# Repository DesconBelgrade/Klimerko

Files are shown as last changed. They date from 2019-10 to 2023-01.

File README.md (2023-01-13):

# “Klimerko” Air Quality Monitoring Station

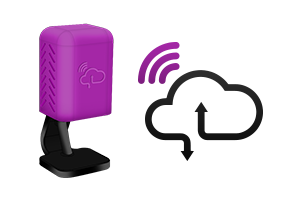
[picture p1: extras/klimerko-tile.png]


"Klimerko" is the continuation of the [Winning Project from Descon 4.0 2018](https://descon.me/2018/winning-product/).  

See live data from all Klimerko devices: [Klimerko.org](https://klimerko.org)

This is an affordable DIY air quality station that measures [Particulate Matter](https://www.epa.gov/pm-pollution/particulate-matter-pm-basics) concentration as well as Temperature, Humidity and Pressure.  
It publishes data to your [AllThingsTalk Maker Cloud](https://www.allthingstalk.com/maker) (free) where you're able to visualize data, see it historically and control the device.   
Continue reading to find out how to build your own, or watch the video below that covers the process.
  
> ***NOTICE:*** The video was created before the release of Klimerko Firmware v2.0.0, which introduced WiFi Configuration Mode, so the process of connecting the device to WiFi and AllThingsTalk shown in the video is outdated.

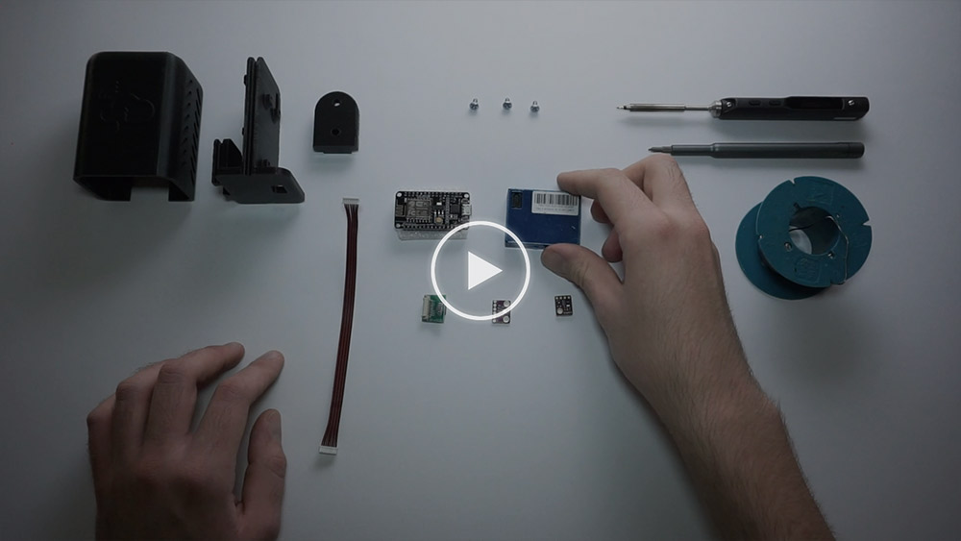
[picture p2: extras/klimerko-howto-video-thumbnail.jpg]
YouTube Video: Kako napraviti klimerka? (https://www.youtube.com/watch?v=D9VHvuHtT14)


**Having issues? Go to the [Troubleshooting](#troubleshooting) section.**  
**To update your Klimerko, go to [Updating Firmware](#updating-firmware)**.

# Table of Contents
This guide is in chronological order, so try not to skip through parts if you're not sure about it.

* [Hardware Build](#hardware-build)
  * [Hardware Required](#hardware-required)
  * [Tools Required](#tools-required)
  * [3D Case Preparation](#3d-case-preparation)
  * [PMS7003 Sensor Preparation](#pms7003-sensor-preparation)
  * [BME280 Sensor Preparation](#bme280-sensor-preparation)
  * [NodeMCU Preparation](#nodemcu-preparation)
* [Cloud Platform (1/2)](#cloud-platform-12)
* [Software](#software)
  * [Installing ESP8266 Support](#installing-esp8266-support)
  * [Uploading Firmware](#uploading-firmware)
  * [Configuring Klimerko Credentials and Temperature Offset](#configuring-klimerko-credentials-and-temperature-offset)
* [Cloud Platform (2/2)](#cloud-platform-22)
  * [Configure Device](#configure-device)
  * [Share Data](#share-data)
  * [Visualize Data](#visualize-data)
* [Updating Firmware](#updating-firmware)
  * [Updating Wirelessly (OTA)](#updating-wirelessly-ota)
  * [Updating using Arduino IDE](#updating-using-arduino-ide)
* [Toubleshooting](#troubleshooting)
  * [Use Serial Monitor](#use-serial-monitor)
  * [Compilation issues](#compilation-issues)
  * [Klimerko can't see WiFi network](#klimerko-cant-see-wifi-network)
  * [Can't connect to Klimerko to configure it](#cant-connect-to-klimerko-to-configure-it)
  * [Klimerko isn't connecting to WiFi or AllThingsTalk](#klimerko-isnt-connecting-to-wifi-or-allthingstalk)
  * [Assets not being updated](#assets-not-being-updated)
  * [Klimerko won't turn on](#klimerko-wont-turn-on)
  * [Factory Reset your Klimerko](#factory-reset-your-klimerko)

# Hardware Build
This diagram shows an overview of how Klimerko works
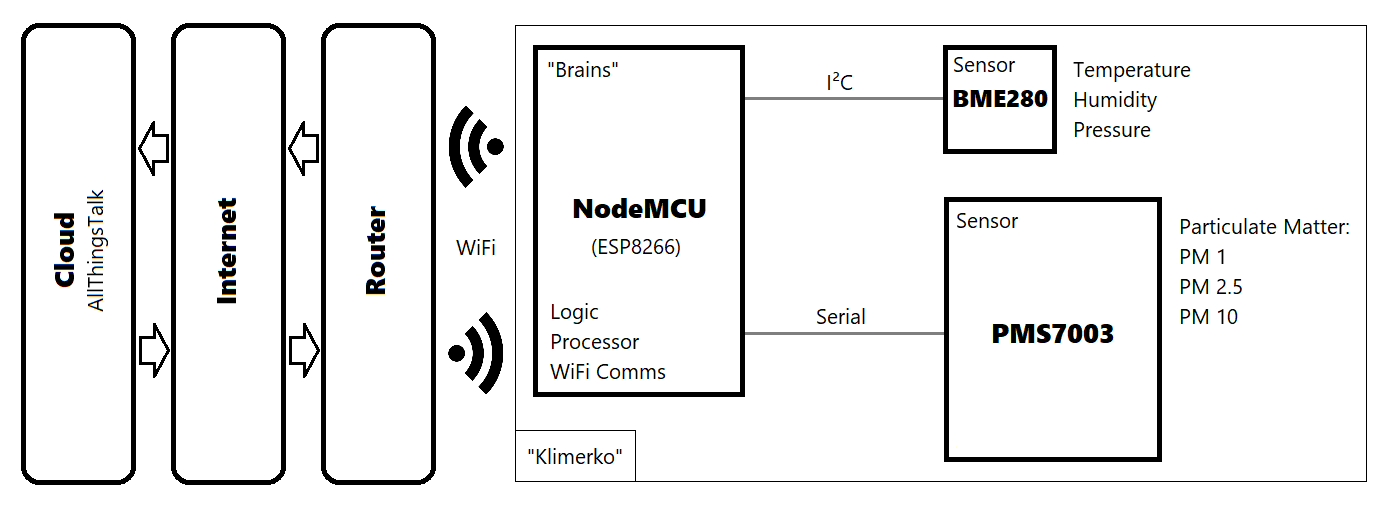
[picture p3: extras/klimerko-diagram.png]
Klimerko Diagram


## Hardware Required

You'll need these components to follow this guide: 

> Previously, some of the components below were clickable so you could buy them right away, but shipping to Balkans on some websites became 10x more expensive than the components themselves, therefore the list now only contains the names, description and a photo of the items you need to buy.  
You can search for these components on [eBay](https://ebay.com), [Banggood](https://banggood.com), [AliExpress](https://aliexpress.com) or your local electronics store/website.

- **NodeMCU (Amica, with CP2102 chip)**  
  Try to avoid the cheapest ones as they're using a different pinout and a weaker CHG340 chip.  
  It should look exactly like this:  
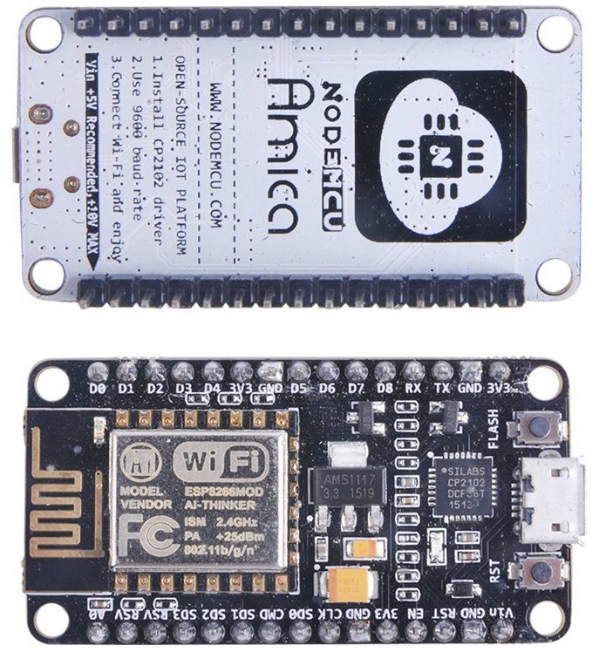
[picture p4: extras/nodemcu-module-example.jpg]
  

- **Plantower PMS7003 Air Quality Sensor**  
  Get the one with a connector and a bridge board.  
  Should look exactly like this:  
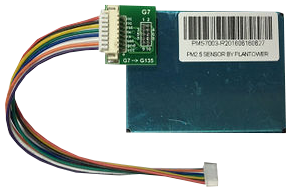
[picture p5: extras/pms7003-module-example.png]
  

- **Bosch BME280 Temperature/Humidity/Pressure Sensor**  
  Make sure to get the BM**E**280 and ***not*** the cheaper BM**P**280.  
  There are variants with 6 pins, and if you find them to be cheaper than the ones with 4 pins (as shown below), you can buy that as well - you just won't use additional 2 pins.  
  It should look exactly like this:  
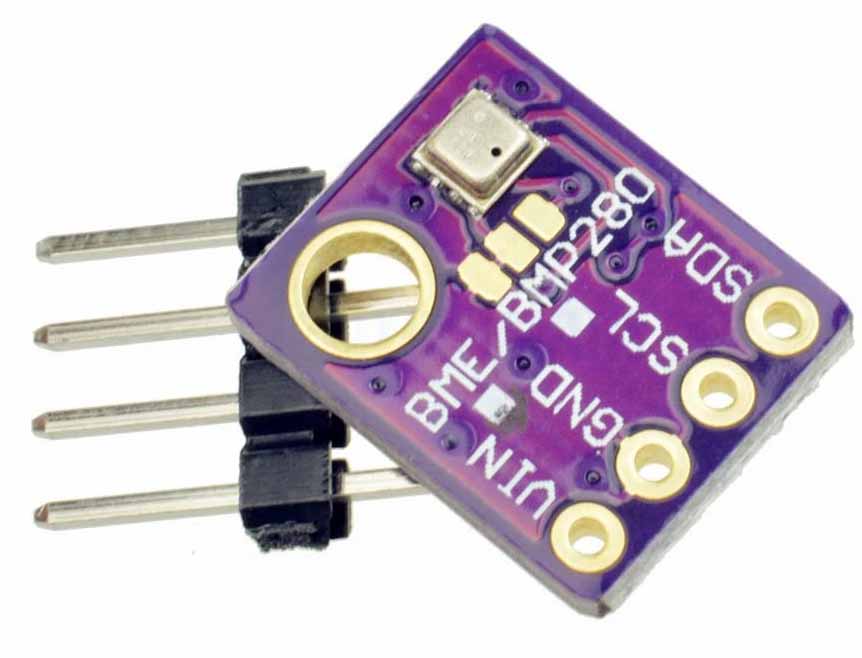
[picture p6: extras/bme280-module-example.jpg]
  

- USB Power adapter (5V, minimum 250mA/0.25A)
- MicroUSB Cable
- **4x** Wires (each at least 13cm long)
- ***Optional:*** 3D printed case for the device ([STL Files](https://github.com/DesconBelgrade/Klimerko/tree/master/Klimerko_Printable_Case)), which comprises of:
    - Components base
    - Weather-resistant cover
    - Flat stand
    - Wall-mount holder
    - Non-3D-Printed: **5x** Screws (for plastic, 3x5mm) (**7**x screws if you’re going to wall-mount the device)

## Tools Required

You’re going to need the following tools at minimum to complete the project:

- Soldering Iron
- Solder
- Scissors or a Wire Stripper
- Screwdriver (required only if using 3D printed case)

## Hardware Assembly

Once you’ve got all the components and tools ready, it’s time to begin the assembly process.  
  
When soldering, make sure that there's no solder between any two pins (connection holes in the board) on any of the components **before** plugging the device into a power source.  
**Pay attention to VIN and GND** pins on the NodeMCU, because shorting (connecting) those two pins together **will fry** NodeMCU and possibly the power source it's connected to.

## 3D Case Preparation

> You can print your own Klimerko Case using a 3D Printer using the [3D Print Files](https://github.com/DesconBelgrade/Klimerko/tree/master/Klimerko_Printable_Case). If you don't have a 3D Printer, your local hacker/makerspace most likely has one!

> In case you're not following this guide at a workshop: 
> You're still able to build this device if you don't have the 3D case. You'll just need to tinker and figure out how to place the device in a secure location away from rain/sun (but in an open space so it can detect pollution properly) 

Depending on your use case, you can use either the flat stand or the wall-mounted holder.
If you wish to wall-mount the device, use 2 screws to mount the holder to a wall. You’ll be able to easily attach and detach the device from the wall.

For now, disassemble the case and put away all the parts except for the components base, where you’ll be placing all the components.

## PMS7003 Sensor Preparation

- First, make sure **not** to remove the blue plastic cover from the PMS7003 sensor as it helps it fit into the 3D case better.
- Place the PMS7003 sensor into the components base of the 3D case with the connection port of PMS7003 facing outwards in upper right side.  
- Plug in the connector cable into the bridge board.  
- Because we don’t need excess cabling, removal of the unnecessary wires from the connector cable is suggested. In order to know which wires to pull, make sure the connector cable is plugged into the bridge board so that you can see the markings on the board that correspond to the wires. To remove the wires, pull them with medium force until they’re detached from the connector. 
These are the wires to pull (marked red):
    - **NC** (first one)
    - **NC** (second one)
    - **RST**
    - **SET**
    The only wires left attached should be **TX**, **RX**, **GND** and **VCC**.

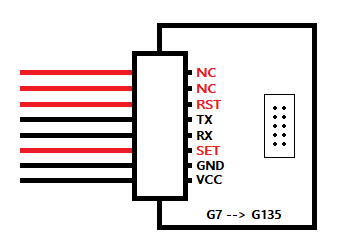
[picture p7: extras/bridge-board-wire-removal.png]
Bridge Board Wire Removal

    
- Measure ~13cm of all 4 remaining wires from the connector cable and cut the rest, so you’re left with the connector at one end and cut wires on the other.
- Using scissors or a wire stripper, remove the insulation ~2mm from the end of each wire, so you’re left with clear copper at the ends.
- Plug the bridge board (with the connector cable in) into the PMS7003 Sensor.
- Route the wires through the circular hole in the components base of the 3D case so it reaches the other side of the base.

## BME280 Sensor Preparation
- Take the 4 wires you have prepared (not to be confused with the PMS7003 wires) and strip (remove insulation) ~2mm from each end of each wire so that you have 4 wires with all ends stripped.
- Solder those 4 wires to pins **SDA**, **SCL**, **GND**, **VCC/VIN** on the BME280.  
  **If you have a 6-pin version of BME280, the CSB and SDO pins simply aren't used.**
- Make sure the PMS7003 Sensor is seated properly (because BME280 goes above it), and only then proceed to the next step.
- Mount the BME280 sensor in place by screwing it to the hole in the upper right side of the 3D case (above the PMS7003).
- Route the wires through the circular hole in the components base of the 3D case so it reaches the other side of the base.

You have now completed the setup of the sensor side of the components base.
Next up, the NodeMCU side.

## NodeMCU Preparation

You should now have 8 wires coming through the circular hole leading to the NodeMCU side of the 3D case.

- Solder the wires to the NodeMCU board:

> Please double check to make sure you’re soldering the correct wires (coming from the sensors) to the NodeMCU board.

| Sensor  | Sensor Wire | NodeMCU Pin |
| --- | --- | --- |
| PMS7003 | VCC | VIN |
| PMS7003 | GND | GND (Any GND pin works) |
| PMS7003 | RX | D6 |
| PMS7003 | TX | D5 |
| BME280  | VCC/VIN | 3v3 (Any 3v3 pin works) |
| BME280  | GND | GND (Any GND pin works) |
| BME280  | SCL | D1 |
| BME280  | SDA | D2 |

> You have now finished all steps that require soldering.

- Now use 4 screws to place the NodeMCU in its spot in the components base of the 3D case.
- Double check all the connections and if everything is as it should be.
- Put the weather-resistant cover of the 3D case over the components base (it's better to do this once everything is done and device is connected, though)

Congratulations, you’ve assembled the device! Now onto the software side.

# Cloud Platform (1/2)
- Head over to [AllThingsTalk Maker](https://maker.allthingstalk.com) and create a free account
- Sign in
- Click “Playground”
- In "Devices", click "+ New Device"
- Choose “Descon Klimerko”
- Click “Settings” in the upper right corner
- Click “Authentication”
- Write down your **Device ID** and **Device Token**

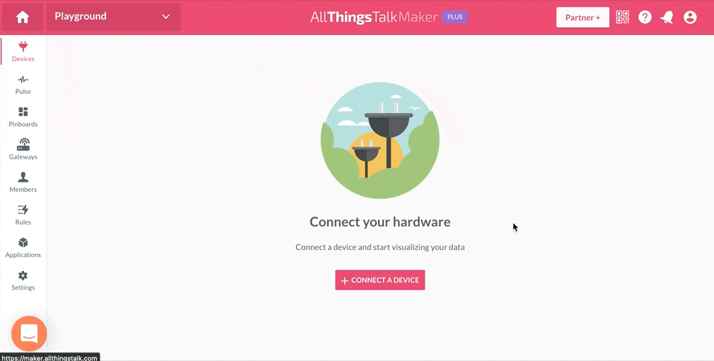
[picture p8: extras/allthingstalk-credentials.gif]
Cloud Credentials


# Software
For all of the steps below, you'll need Arduino IDE (Integrated Development Environment).  
This is a tool that's used to send the "firmware" or "program" to your device.  

> If you already have Arduino IDE, make sure it's **at least** version 1.8.15

- Download and install [Arduino IDE](https://www.arduino.cc/en/software) 
(choose “*Windows installer, for Windows XP and up*” if you’re on Windows, otherwise it'll download the Windows Store version, which might give you issues).

- If you're on **Microsoft Windows**, [download and install the CP2102 Driver for Windows](https://www.silabs.com/documents/public/software/CP210x_Universal_Windows_Driver.zip).

- If you're on **Apple's MacOS**, [download and install the CP2102 Driver for MacOS](https://www.silabs.com/documents/public/software/Mac_OSX_VCP_Driver.zip).

## Installing ESP8266 Support
ESP8266 is the "brains" or "processor" of the NodeMCU, but Arduino IDE doesn't support it out-of-the-box. That's an easy one:
- Open Arduino IDE
- Go to *File* > *Preferences*
- In the *Additional Boards Manager URLs*, enter `http://arduino.esp8266.com/stable/package_esp8266com_index.json` and click *OK*
- Go to *Tools* > *Board* > *Boards Manager*
- Search for “*esp8266*” by *ESP8266 Community*
- Click *Install*
- Once done, close the window.

## Uploading Firmware
Your NodeMCU's "brain" is empty at the moment. Let's teach it what it needs to do by uploading the program to it:

- Plug in the USB cable into your Klimerko device and your computer
- Download https://github.com/DesconBelgrade/Klimerko/archive/master.zip
- Unzip the file, open it and go to “Klimerko_Firmware” folder
- Open “Klimerko_Firmware.ino” with Arudino IDE
- Now go to *Tools* > *Board* and choose “*NodeMCU 1.0 (ESP-12E Module)*”
- Go to *Tools* > *Upload Speed* and choose *115200*
- Go to *Tools* > *Port* and you should see **COM** and a number next to it. Choose it.
  - If you have multiple COM ports available and the one you've chosen doesn't work, try the other ones as well.
  - If you're running **MacOS**, choose */dev/cu.SLAB_USBtoUART*
- Go to “Sketch” > “Upload” and wait for the firmware to be uploaded to your Klimerko device

## Configuring Klimerko Credentials and Temperature Offset
> Since Klimerko Firmware version 2.0.0, the process of entering WiFi & Platform credentials has been immensely simplified by introducing WiFi Configuration Mode, a feature where Klimerko itself becomes a WiFi Access Point to which you can connect to using your computer or smartphone and then configure the credentials using a simple web interface that opens up automatically once you're connected to your Klimerko.  

You need tell your Klimerko which credentials to use to connect to the platform and to which WiFi to connect to: 

- Make sure your Klimerko is connected to power.
- Lift your Klimerko's cover to expose the NodeMCU board.
- Press and hold the **FLASH** button for 2 seconds and then let go.
- The blue LED on the NodeMCU should turn on and stay on. This indicates the WiFi Configuration Mode is currently active and you can connect to your Klimerko.
- Using your computer or a smartphone, search for and connect to WiFi Network ***"KLIMERKO-XXX"*** (the X's are numbers) using password **"ConfigMode"**.
- Your device should automatically open Klimerko's WiFi Configuration Portal. If it doesn't, navigate to **[192.168.4.1](http://192.168.4.1)** in your browser. 
- Click the first **"Configure WiFi"** button.
- A list of available WiFi Networks will be shown, along with a field to enter your AllThingsTalk Device ID and Device Token.
  > NodeMCU only supports 2.4GHz, so make sure the network you're trying to connect your Klimerko to **is not** a 5GHz network.
- Select your WiFi network from the list (or manually enter WiFi network name if you're not in range of the network you plan to use your Klimerko on), enter your WiFi Password and copy/paste the AllThingsTalk Device ID and Device Token that you noted in previous step ([Cloud Platform Credentials](#cloud-platform-12))
  > If you are updating your credentials, it is possible to only update some of them by leaving other fields empty. The empty fields will not overwrite the values stored in memory when saving.
- You can set a custom **Temperature Offset** if you wish. This will affect temperature readings from the device and humidity readings will be compensated for the temperature offset as well.
  > Configurable Temperature Offset has been introduced in Firmware Version 2.1.0. The default offset is `-4°C`. Decimals, negative and positive values are supported (e.g. `-1.2`, `3.58`, `+3.58`, `-7.43`). Positive values can be set with or without the `+` prefix. The maximum positive offset is 25°C, and maximum negative is -25°C. If you wish to use the default value, simply leave the **Temperature Offset** field as it is. As opposed to WiFi Credentials and AllThingsTalk Credentials, the Temperature Offset field always displays the currently used value.
- Click ***"Save"***. 
- Klimerko has now automatically shut down the WiFi Configuration Mode (the blue LED stops shining constantly) and your computer/smartphone will disconnect from "KLIMERKO-XXX" network. The WiFi Configuration Portal will automatically close on your computer/smartphone only if it was automatically opened. Otherwise, you'll need to close the browser tab.
- Your Klimerko will now attempt to connect to WiFi and AllThingsTalk, indicated by slow blinking of the LED light.
- Observe the LED on the NodeMCU. If it blinks quickly a few times and then turns off completely, your Klimerko is connected to both WiFi and AllThingsTalk. Otherwise, repeat the process (the credentials could be incorrect) or check the [Troubleshooting section](#troubleshooting).

> The blue LED light on NodeMCU blinks slowly (in 1 second intervals) when Klimerko is trying to connect to WiFi or AllThingsTalk (or if the connection can't be established).  
If it blinks rapidly a few times and then turns off, the connection to WiFi and AllThingsTalk has been made succesfully.  
If it's turned on constantly, it means the WiFi Configuration Mode is currently active and you can connect to your Klimerko using your smartphone.  
If you wish to turn off WiFi Configuration Mode without configuring your Klimerko, press the ***"FLASH"*** button on your NodeMCU quickly, once. The constant blue LED should turn off.

# Cloud Platform (2/2)

All of the data from your Klimerko is available on your AllThingsTalk Maker.  
Other than raw actual and historical air quality values, you’re able to see your air quality in a textual form at a glance, see the WiFi Signal Strength of your Klimerko and control how often your Klimerko publishes data.  
You’ll also get notifications if your Klimerko goes offline for any reason.

## Configure Device

Open [AllThingsTalk Maker](https://maker.allthingstalk.com), go to “Devices” and select your new “Descon Klimerko” device.  
You’ll see all assets of your device (stuff that it can report and things you can control).

> Make sure to keep the data (that you’re about to set below) updated if you move your device

- Click on the “Location” asset and select the location of your Klimerko on the map
- Click on the “Height” asset and set the height of your device (in **meters**) by adding a value right next to `"value":`  and clicking the ✔️ button when done (below is an example of 10 meters height):
```
    {
        "at": "2019-10-18T11:28:04.554Z",
        "value": 10
    }
```
This needs to be done since air pollution readings are different on different heights.

## Share Data

Go to your “Decon Klimerko” device, click “Settings” in the upper right corner, go to “Share data” and share your data with “**Vazduh gradjanima**”.  
Your device will now be visible on the map at [Klimerko.org](https://klimerko.org) and can help the community be aware of the air quality!  

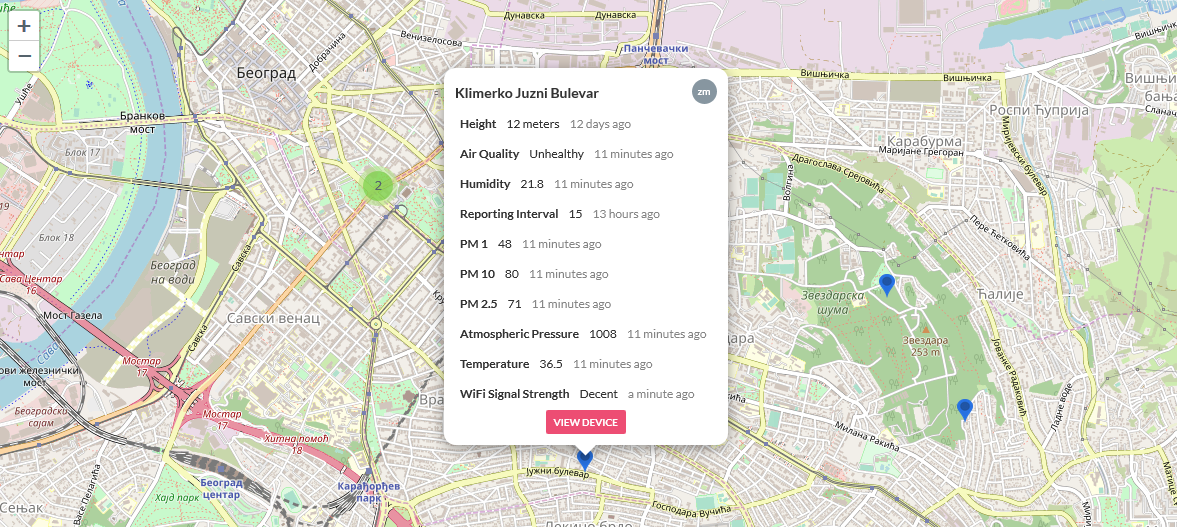
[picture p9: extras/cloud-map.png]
Cloud Map
 

## Visualize Data

Now go to “Pinboards” on the left side of AllThingsTalk Maker.  
You should see a new pinboard named “Klimerko”. Select it if it isn’t already selected.  
All data from your Klimerko is visualized here:

- Air Quality (in textual form)  
    Value shown will also have a corresponding background color.  
    This value is derived from PM10 values (as per [regulations of Republic of Serbia](http://www.amskv.sepa.gov.rs/kriterijumi.php)):
    
| Textual Value | PM 10 Value |
| --- | --- |
| Excellent | 0 - 20 |
| Good | 21 - 40 |
| Acceptable | 41 - 50 |
| Polluted | 51 - 100 |
| Very Polluted | 100 > |

- Actual PM1, PM2.5, PM10, Temperature, Humidity and Pressure data
- Historical PM1, PM2.5, PM10, Temperature, Humidity and Pressure data
- Location of your device on the map (that you’ve set)
- WiFi Signal Strength of your Klimerko device  
    Possible values (from good to bad): Excellent, Good, Decent, Bad, Horrible.  
    The values shown will also have a corresponding background color.
- Device height (that you’ve set)
- Device reporting interval (minutes)  
    You can use this slider to control how often your Klimerko reports its data to AllThingsTalk. The default and recommended value is 15 minutes.

**You’re done!**  
Enjoy your device and feel free to visit [Klimerko.org](https://klimerko.org) and see your device along with all the other devices just like yours that are helping others be aware of the air pollution in your area!

# Updating Firmware
This step is for those who've already built their Klimerko and wish to update its firmware to the latest version.  

To check what Firmware version your Klimerko is on, you can:
  - Open your Klimerko device on your [AllThingsTalk Maker](https://maker.allthingstalk.com):  
  The Firmware Version will be stored in the "Firmware Version" asset.  
  - Use Serial Monitor in Arduino IDE:  
  Klimerko will output the Firmware Version in the first few lines once it boots.
  - *Version 2.0.0 and above only:* Activate WiFi Configuration Mode  and click **Configure WiFi**:  
  The Firmware Version will be written in the bottom part of the page.  
  To exit WiFi Configuration Mode, go back and click "EXIT" or click the **FLASH** button once on NodeMCU.  

> If you are updating from a version before 2.0.0 to version 2.0.0 or above, you'll need to [re-enter the credentials](#configuring-klimerko-credentials) once you've updated your device.  
This only applies to aforementioned cases due to changes in how data is stored in firmwares 2.0.0 and above.

## Updating Wirelessly (OTA)
> Use this method if your Klimerko is currently on firmware version 2.0.0 or above.
- Download ***[Klimerko_Firmware.bin](https://github.com/DesconBelgrade/Klimerko/raw/master/Klimerko_Firmware/Klimerko_Firmware.bin)***
- Connect your Klimerko to power.
- Take off the 3D printed cover (if present).
- Enter WiFi Configuration Mode by holding the ***"FLASH"*** button on the NodeMCU board for 2 seconds and then let go (Klimerko's LED should turn on and stay solid blue, indicating WiFi Configuration Mode is on).
- Using your computer/smartphone, connect to WiFi Network  **"KLIMERKO-XXX"** using password **"ConfigMode"**
- Klimerko's WiFi Configuration Portal may automatically open outside of your browser once you connect to it - ignore it in this case.
- Open the browser on your computer/smartphone and navigate to **[192.168.4.1](http://192.168.4.1)** to manually open WiFi Configuration Portal.
- Click the  **UPDATE** button.
- Click **Browse** and select the *"Klimerko_Firmware.bin"* file you downloaded earlier.
- Click the red **UPDATE** button and wait for it to confirm that the update is finished.
- Your Klimerko will reboot.

## Updating using Arduino IDE
> Use this method if your Klimerko is on a firmware older than v2.0.0 or you're having issues with Over-The-Air updating.
- Plug in the USB cable into your Klimerko and your computer
- [Download the latest Klimerko Firmware](https://github.com/DesconBelgrade/Klimerko/archive/master.zip)
- Unzip the file, open it and go to “*Klimerko_Firmware*” folder
- Open “*Klimerko_Firmware.ino*” with Arudino IDE
- Make sure you're running at least Arduino IDE version 1.8.15
  - If on Windows, click *Help > About Arduino* to check version
  - If on MacOS, click *Arduino > About Arduino* to check version
  - In case you're on a version older than 1.8.15, simply download [Arduino IDE](https://www.arduino.cc/en/Main/software) again and install it.
    - If on Windows, choose “*Windows installer, for Windows 7 and up*” when downloading
- Go to *Tools* > *Board* > *Boards Manager*
- Search for “*esp8266*” by *ESP8266 Community* and click "Install" or "Update" if you already have it installed.
  - If for some reason you don't see the search result, make sure you've [installed ESP8266 support](#installing-esp8266-support)
- Now go to *Tools* > *Board* and choose “*NodeMCU 1.0 (ESP-12E Module)*”
- Go to *Tools* > *Upload Speed* and choose *115200*
- Go to *Tools* > *Port* and you should see **COM** and a number next to it. Choose it.
  - If you have multiple COM ports available and the one you've chosen doesn't work, try the other ones as well.
  - If you're running **MacOS**, choose **/dev/cu.SLAB_USBtoUART** or **/dev/cu.usbserial-0001** (if you don't see it, install [the driver first](https://www.silabs.com/documents/public/software/Mac_OSX_VCP_Driver.zip))
- Go to *Tools* > *Erase Flash* > *Only Sketch*
- Go to “Sketch” > “Upload” and wait for the firmware to be uploaded to your Klimerko device
- ***Optional:*** Open Serial Monitor (*Tools > Serial Monitor*), set it to 115200 baud rate and check Klimerko diagnostic output to see if everything is working.

Awesome! Your Klimerko is now updated to the latest version!

# Troubleshooting
## Update to newest firmware
Before anything else, make sure you've updated your Klimerko to the newest Firmware by following the [Updating Firmware](#updating-firmware) section.

## Use Serial Monitor
To see what's really going on under the hood, use the Serial Monitor tool provided in Arduino IDE:
  - Connect your Klimerko to your computer
  - Open Arduino IDE
  - Select *Tools > Port* and select the correct port
  - Go to *Tools > Serial Monitor* in Arduino IDE
  - You will now see diagnostic output from your Klimerko.  

If your device is showing unintelligible text in Serial Monitor:
  - Make sure your Serial Monitor is set to baud rate of 115200 (set this in the bottom right corner of Serial Monitor)  

## Compilation issues
If you're having compiling issues (orange errors in the bottom of Arduino IDE), make sure that:
  - Your Arduino IDE is at least version **1.8.15**
  - You've downloaded the latest firmware from https://github.com/DesconBelgrade/Klimerko/archive/master.zip
  - You've selected the correct board and port as shown [here](#upload-firmware)
  - You're running the latest version of ESP8266 Core
    - In Arduino IDE, go to *Tools* > *Board* > *Boards Manager*
    - Search for “*esp8266*” by *ESP8266 Community*
    - Click the **Update** button shown next to the result (if you don't see it, you're probably running the latest version).

## Klimerko can't see WiFi network
  - Make sure the network you're trying to connect your Klimerko to is a 2.4GHz network, and not a 5GHz one as NodeMCU only supports 2.4GHz.
  - Make sure you're in range.

## Can't connect to Klimerko to configure it
If you can't connect to your Klimerko when it's in WiFi Configuration Mode or you can't open WiFi Configuration Portal (192.168.4.1):
  - Disconnect and reconnect to "KLIMERKO-XXX" WiFi Access Point and try again
  - Forget the "KLIMERKO-XXX" WiFi network on your device and try connecting again (password is "ConfigMode")
  - Turn off WiFi on your device, wait a few seconds, and then turn it back on and try again

## Klimerko isn't connecting to WiFi or AllThingsTalk
If your device won't connect to WiFi or AllThingsTalk (blue LED on NodeMCU constantly blinking slowly):
  - If you updated your Klimerko's Firmware from a version below 2.0.0 to version 2.0.0 or above, you will need to [re-enter your WiFi and AllThingsTalk credentials](#configuring-klimerko-credentials) just this time, as noted in [Updating Firmware](#updating-firmware).
  - Make sure your credentials are correct. Check if you copied your [AllThingsTalk credentials](#cloud-platform-12) and your WiFi credentials correctly. [Reconfigure credentials to make sure.](#configuring-klimerko-credentials)  
    - If you only need to update WiFi Credentials, you can leave "AllThingsTalk Device ID" and "AllThingsTalk Device Token" fields empty when saving.
    - If you only need to update AllThingsTalk Credentials, you can leave the WiFi fields empty when saving.
    - If you only need to update "AllThingsTalk Device ID", you can leave WiFi and "AllThingsTalk Device Token" fields empty when saving.
    - If you only need to update "AllThingsTalk Device Token", you can leave WiFi and "AllThingsTalk Device ID" fields empty when saving.
  - Turn on WiFi Configuration Mode on your Klimerko by pressing and holding the **FLASH** button on the NodeMCU board.  
  Connect to your Klimerko using WiFi and once the WiFi Configuration Portal is open, you should see the WiFi connection status at the bottom of the page.
  - Make sure Klimerko is not too far away from your Router.
  - Make sure your Router has internet access.

## Assets not being updated
If your device is connected, but some assets are not being updated (or only "Interval", "WiFi Signal" and "Firmware Version" assets are being updated):
  - This means one or both of your sensors aren't connected.
  - If assets "PM1", "PM2.5", "PM10" and "Air Quality" aren't being updated, your PMS7003 sensor isn't connected properly.
  - If assets "Temperature", "Humidity" and "Pressure" aren't being updated, your BME280 sensor isn't connected properly.
  - [Check your wiring](#hardware-assembly) to make sure everything is connected properly.
  - Make sure that there's no solder between any two pins on the board (either the NodeMCU or the BME280 sensor). If this is the case, it is causing a short-circuit and could break the device.
  - Make sure that you haven't removed too much insulation from the wires. In this case, one wire could be touching another wire with the exposed part, causing a short-circuit. If that's the case, de-solder the wire, cut it shorter (only 2mm or less should be exposed before soldering) and solder it back.

## Klimerko won't turn on
  - The NodeMCU has a blue LED right above the small shiny metallic box. That LED blinks for a brief moment right when you plug the device into power. If yours doesn't blink when you plug it in, check the USB cable (and try another one if you have it). If that makes no difference, check the power supply (the adapter).
  - Make sure that there's no solder between any two pins on the board (either the NodeMCU or the BME280 sensor). If this is the case, it is causing a short-circuit and could break the device. 
  - Make sure that you haven't removed too much insulation from the wires. In this case, one wire could be touching another wire with the exposed part, causing a short-circuit. If that's the case, de-solder the wire, cut it shorter (so only 2mm or less is exposed) and solder it back.

## Factory Reset your Klimerko
  - Press and hold the ***FLASH*** button on the NodeMCU board for at least 15 seconds.
  - The blue LED should flash rapidly for 2 seconds and then stay on.
  - Your Klimerko has now deleted all credentials and temperature offset data from itself and will restart shortly.
  - Once the LED turns off, Klimerko has been restarted.
  - The LED will now blink slowly, indicating it's trying to connect to WiFi and AllThingsTalk (but it can't, since there's no credentials)
  - You can now follow [Configuring Klimerko Credentials and Temperature Offset](#configuring-klimerko-credentials-and-temperature-offset) again.

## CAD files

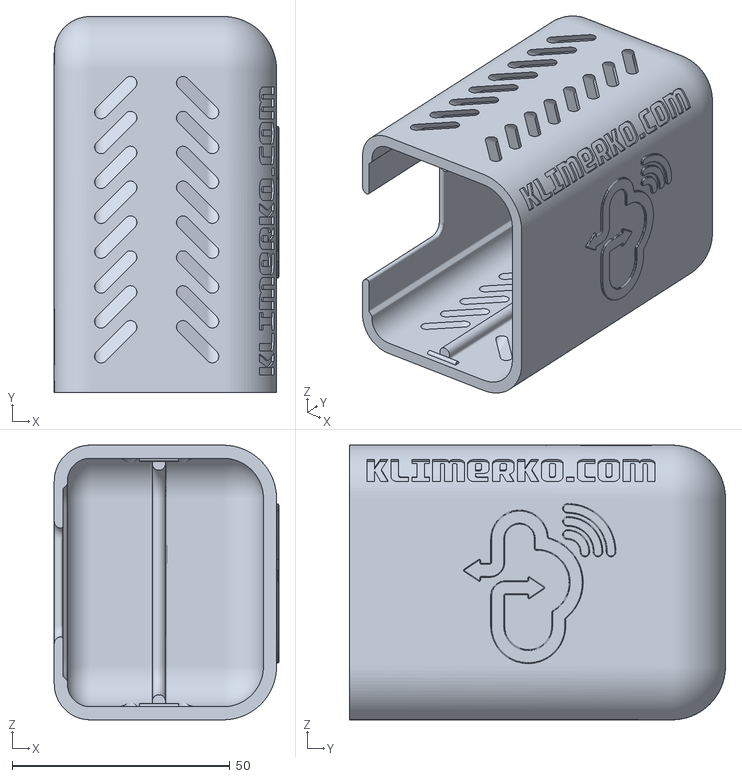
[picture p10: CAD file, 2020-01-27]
Klimerko_Printable_Case/Housing/Cover.STL
51.5 x 86.2 x 63.0

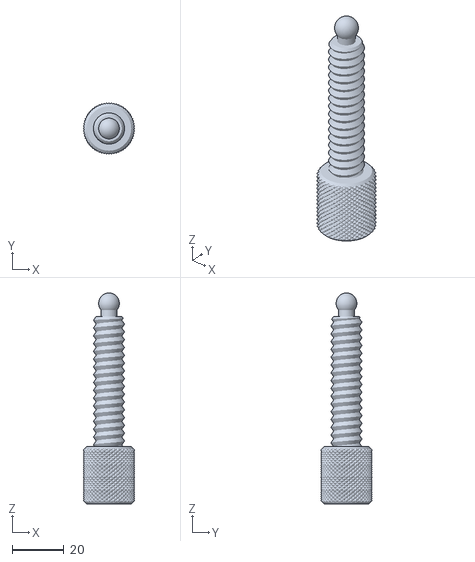
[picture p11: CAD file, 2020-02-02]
Klimerko_Printable_Case/Mounting/Clamp Mount/Clamp Thread.stl
19.8 x 19.8 x 81.3

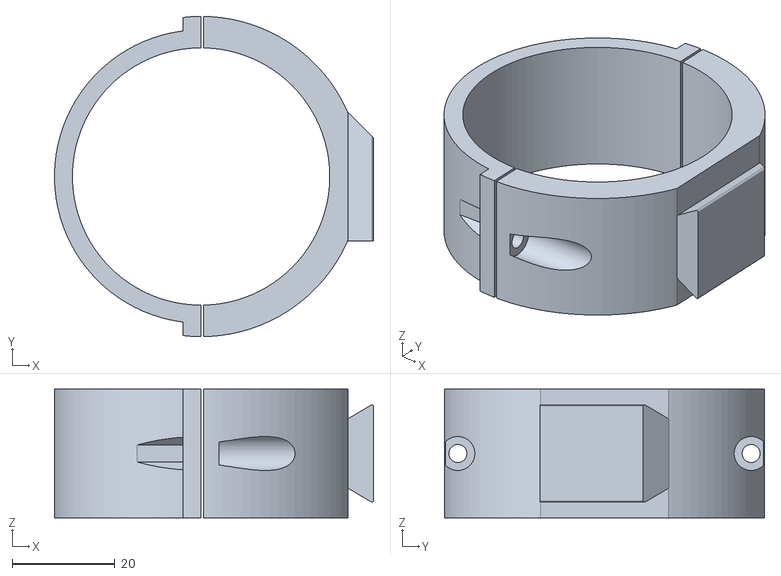
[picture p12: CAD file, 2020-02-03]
Klimerko_Printable_Case/Mounting/Pole Mount/Pole Mount (Round, Horizontal, 50mm).stl
62.0 x 62.2 x 25.0

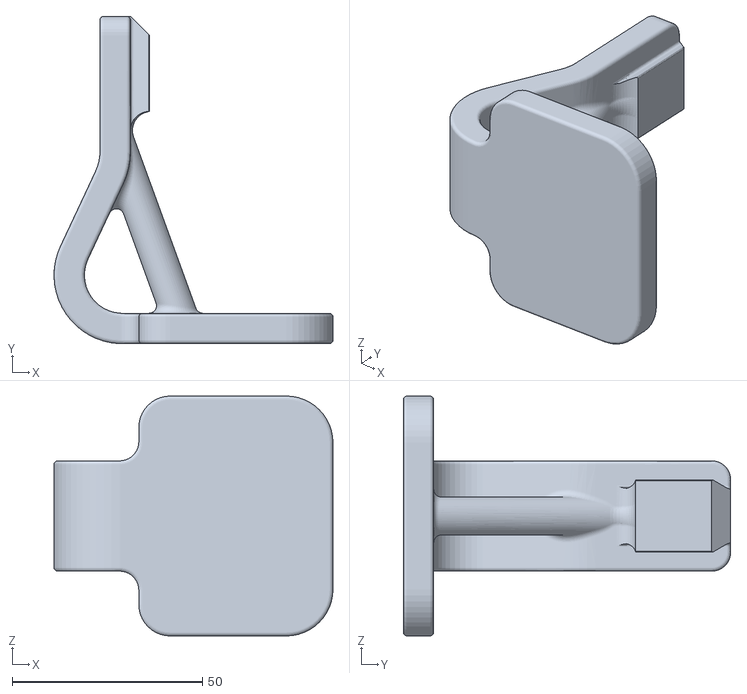
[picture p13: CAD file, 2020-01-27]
Klimerko_Printable_Case/Mounting/Table Stand.STL
73.3 x 86.0 x 63.0

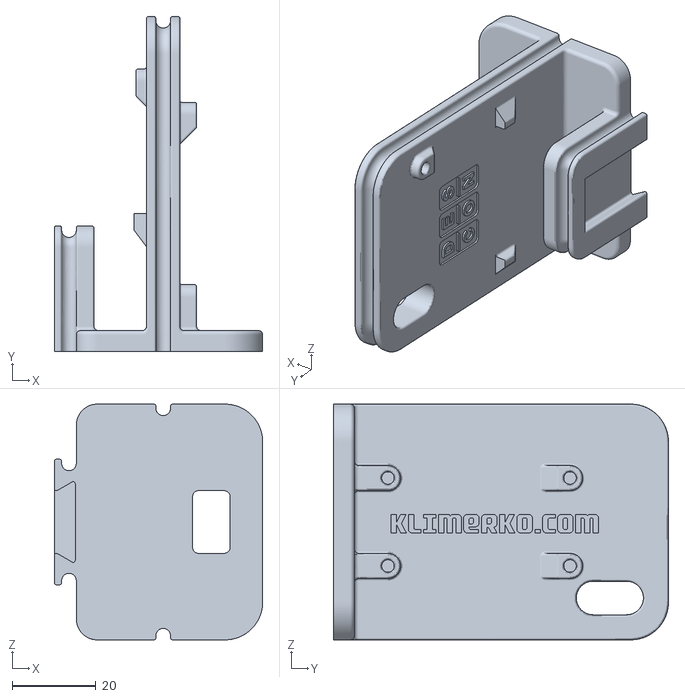
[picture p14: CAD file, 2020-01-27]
Klimerko_Printable_Case/Housing/Base.STL
49.8 x 80.0 x 56.3

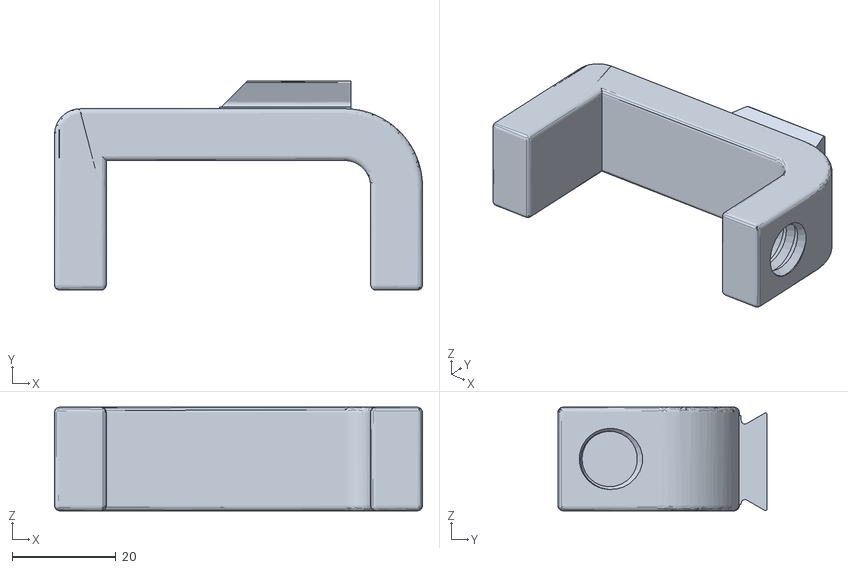
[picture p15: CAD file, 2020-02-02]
Klimerko_Printable_Case/Mounting/Clamp Mount/Clamp Mount.stl
71.0 x 40.4 x 20.0

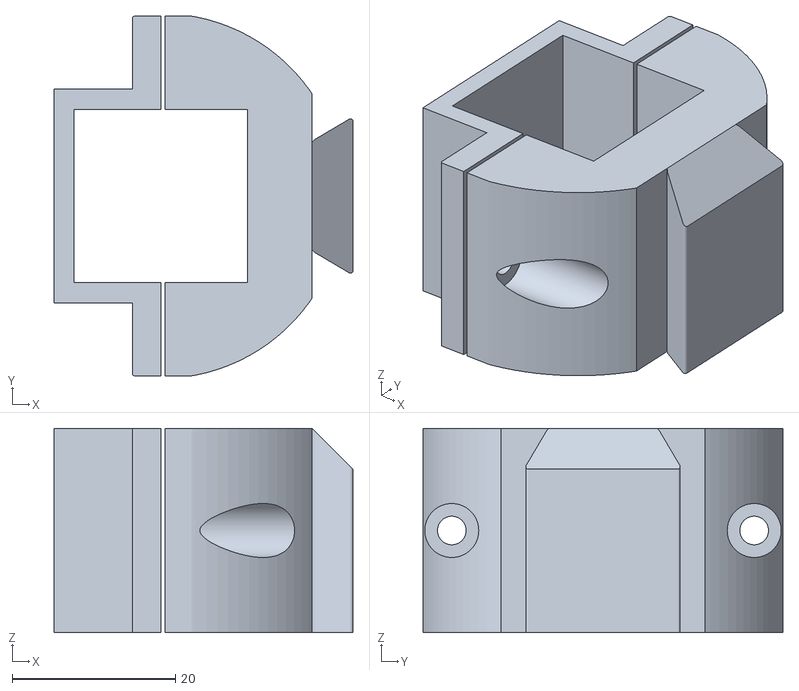
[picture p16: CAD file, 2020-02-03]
Klimerko_Printable_Case/Mounting/Pole Mount/Pole Mount (Square, Vertical, 30mm).stl
36.6 x 44.0 x 25.0

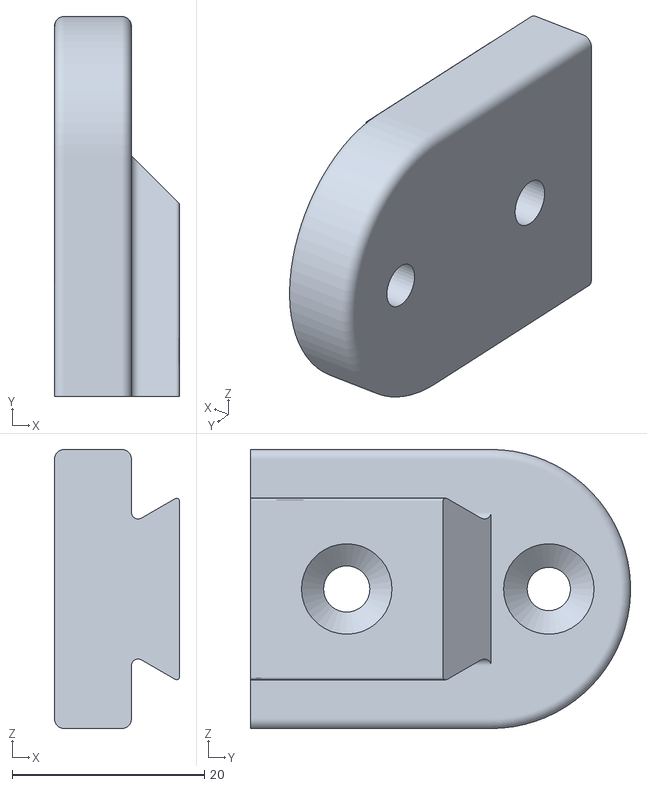
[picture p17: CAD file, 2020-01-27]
Klimerko_Printable_Case/Mounting/Wall Mount.STL
13.0 x 39.5 x 29.0

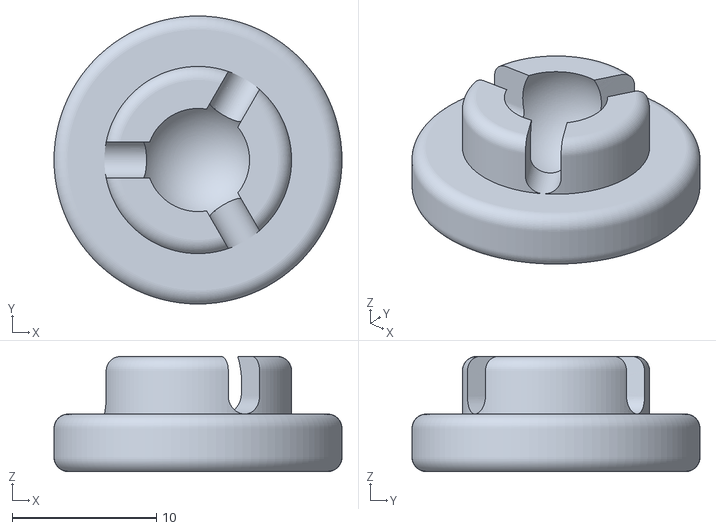
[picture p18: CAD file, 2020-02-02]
Klimerko_Printable_Case/Mounting/Clamp Mount/Clamp Protector.stl
20.0 x 20.0 x 8.00

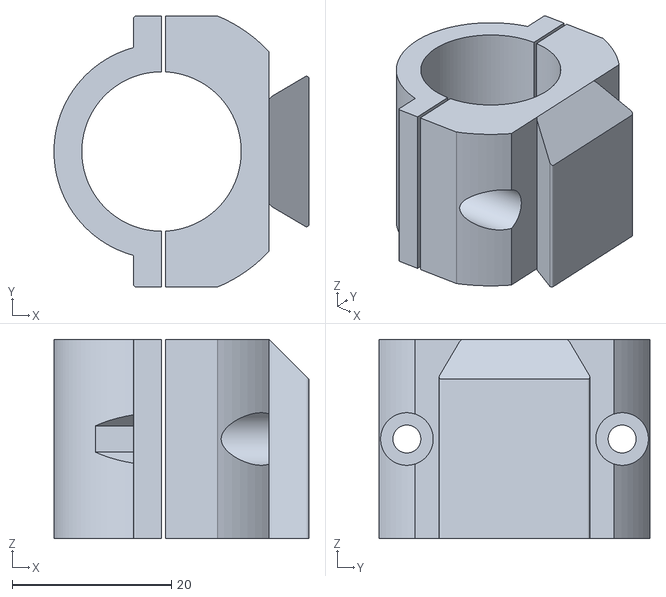
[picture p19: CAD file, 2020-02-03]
Klimerko_Printable_Case/Mounting/Pole Mount/Pole Mount (Round, Vertical, 20mm).stl
32.0 x 34.0 x 25.0

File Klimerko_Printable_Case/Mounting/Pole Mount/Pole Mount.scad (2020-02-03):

/*
    Pole mount for DESCON Klimerko device (https://github.com/DesconBelgrade/Klimerko).
    By Filip Vranesevic.
    INSTRUCTIONS:
    To generate customized mount open this file in OpenSCAD application (www.openscad.org)
    and modify the parameters below. Select "Render" from "Design" menu (or F6) and then 
    "Export->Export as STL..." from "File" menu (or F7) to generate STL file for printing.
*/

/*================================ Prameters to modify ===================================*/

pole = 20;          // Diameter of the pole to attach to 

wall = 3.5;         // Thickness of the mount brace. For small pole diameter use bigger
                    // brace thickness so the mount is big enough to mount the device.
                    
horizontal = false; // Is the pipe horizontal (set true) or vertical (set false)

pole_angle = 45;    // angle by which pole is rotated in relation to the device mount.
                    // Does not have an effect on circular pole.

num_angles = 100;   // The shape of the pole can be any regular polygon. This variable 
                    // sets the number of angles for polygon (eg. 3 for triangle, 4 for  
                    // square, 5 for pentagon...) For circle use some high number like 100.

len = 25;           // The length of the mount on the pole

/*========================================================================================*/


// Internal variables, do not modify unless you know what are you doing
$fn = 100;
dt_w = 18.9;
dt_n = 13.8;
dia = 0.6;
rad = dia/2;
depth = 5;
plate_w = 25;
D2 = pole+(2*wall);
thickness = D2/2;
    
module mount()
{

    width = D2;
    D3 = sqrt(pow(plate_w/2, 2) + pow(D2/2,2))*2;
    offset = (D2-dt_w)/2;

    difference() {
        union() {

            // Main body
            intersection() {
                hull() {
                    translate([rad-wall,0,rad-wall])
                        rotate([90,0,0])
                            cylinder(d=dia, h=len);
                    translate([thickness-rad,0,rad-wall])
                        rotate([90,0,0])
                            cylinder(d=dia, h=len);
                    translate([rad-wall,0,width-rad+wall])
                        rotate([90,0,0])
                            cylinder(d=dia, h=len);
                    translate([thickness-rad,0,width-rad+wall])
                        rotate([90,0,0])
                            cylinder(d=dia, h=len);
                }
                translate([0,0,width/2])
                    rotate([90,0,0])
                        cylinder(d=D3, h=len);
            }

            // Brace
            translate([0,0,width/2])
                rotate([90,pole_angle,0])
                    cylinder(d=D2, h=len, $fn=num_angles);
            
            // Dovetail
            if (horizontal) {
                translate([thickness,-len/2-dt_w/2,width/2-len/2])
                    rotate([-90,0,0])
                        dovetail();
            } else {
                translate([thickness,0,offset])
                    dovetail();
            }
        }
        
        union () {
            
            // Pole hole
            translate([0,0,width/2])
                rotate([90,pole_angle,0])
                    cylinder(d=pole, h=len,$fn=num_angles);
            
            // Gap
            translate([0,-len,-wall])
                cube([0.5, len, D2+(2*wall)]);
            
            // Screw holes
            translate([-D2/2-wall, -len/2, 0])
                rotate([0,90,0])
                    screw();
            translate([-D2/2-wall, -len/2, D2])
                rotate([0,90,0])
                    screw();
        }
    }
}

module screw()
{
    cylinder(d=3.5, h=D2+wall);
    rotate([0,0,30])
        cylinder(d=6.6, h=D2/2, $fn=6);
    if (horizontal) {
        translate([0,0,D2/2+(2*wall)])
            cylinder(d=6.6, h=thickness-wall+depth);
    } else {
        translate([0,0,D2/2+(2*wall)])
            cylinder(d=6.6, h=D2/2-wall);
    }
}


module dovetail()
{
    mid = (dt_w-dt_n)/2;
    difference() {
        translate([rad,0,rad]) {
            hull() {
                translate([depth-dia,0,0])
                    rotate([90,0,0])
                        cylinder(d=dia, h=len);
                translate([depth-dia,0,dt_w-dia])
                    rotate([90,0,0])
                        cylinder(d=dia, h=len);
                translate([0,0,0+mid])
                    rotate([90,0,0])
                        cylinder(d=dia, h=len, $fn=4);
                translate([0,0,dt_n-dia+mid])
                    rotate([90,0,0])
                        cylinder(d=dia, h=len, $fn=4);
            }
        }
        rotate([0,0,-45])
            cube([depth*2, depth*2, dt_w]);
    }   
}


rotate([90,0,0])
    mount();

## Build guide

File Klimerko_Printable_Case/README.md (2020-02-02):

# Files for 3D Printing the Klimerko Case and Mounts/Holders

- "**Housing**" folder contains files to create a functional case for your Klimerko
- "**Mounting**" folder contains multiple types of mounts and holders, so use the one that fits you best :)

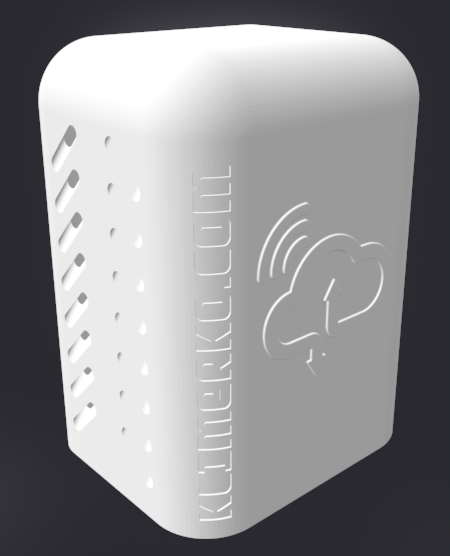
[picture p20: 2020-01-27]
extras/printable-case-3.png

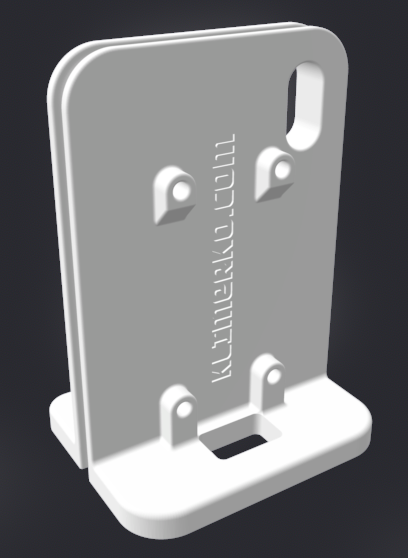
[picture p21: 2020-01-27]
extras/printable-case-2.png

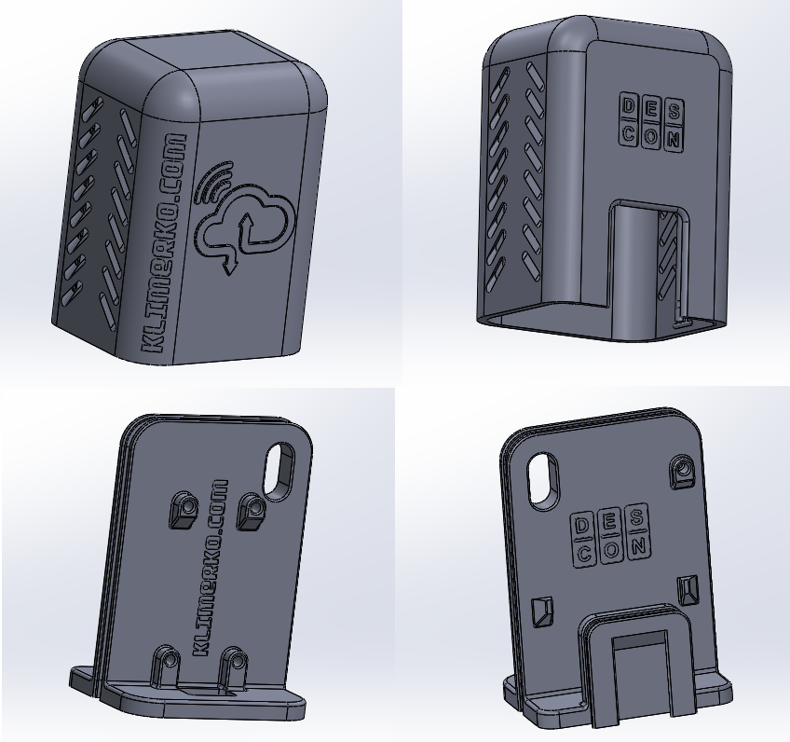
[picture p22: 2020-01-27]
extras/printable-case-1.png

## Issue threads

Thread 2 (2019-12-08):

3D case instruction

mletic, 2019-12-08:
Is there any way to order the 3D case?
Or at least to get the 3D model and the relevant info so we can print it somewhere?

Btw keep up the good work!

DesconBelgrade, 2019-12-09:
There isn't right now, but it'll be available in the near future!
And thanks :)

epiller, 2020-01-28:
Hey, thought I'd you know that the required to 3D print the case yourself have just been published and you can check them out [here!](https://github.com/DesconBelgrade/Klimerko/tree/master/Klimerko_Printable_Case)

Closed 2019-12-09.

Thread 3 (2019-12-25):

Hiding sensors that do not have current data from vazduhgradjanima.rs

milos1986, 2019-12-25:
Default map view should imho hide the sensors with old PM data. Data older than e.g. 2h is arguably not useful for the visitors seeking current pollution data. Old data makes it harder to find current pollution data, as one needs to click around to find "alive" sensors. A feature request and the ideal case would be to display air quality for each sensor on the map directly, along with the time of measurement. A filter enabling one to define what "current data" is (e.g., 1h or 3h old) could be another nice feature.

epiller, 2020-01-26:
I agree with you. This is on our roadmap and will be addressed.

Closed 2020-01-26.

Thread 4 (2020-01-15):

3d printer .stl files would be nice :)

retro-source, 2020-01-15:
3d printe .stl files would be nice :)

dcabro, 2020-01-17:
Or any other acceptable file format for that matter. If anyone is willing to share their file, that'd be awesome. Thanks!

epiller, 2020-01-27:
The STL files will be published and available for download somewhere before 15th of February :)

epiller, 2020-01-28:
[It's available right now!](https://github.com/DesconBelgrade/Klimerko/tree/master/Klimerko_Printable_Case)

dcabro, 2020-01-28:
Thank you so much! Awesome!

You might want to further clarify that you don't need both Stand and Wall Mount, but you pick one depending on the mounting desires. Keep up the good work!

Closed 2020-01-27.

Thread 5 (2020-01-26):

BME280

kanazir, 2020-01-26:
Please update Aliexpress link to some other item. The listed item is not BME but BMP which can't measure humidity.

epiller, 2020-01-26:
How did you figure? I just checked the link again and it's the BME280.
If you were judging by the PCB of the sensor itself, it does contain a marking saying "BMP/BME280" which is meant for resellers to tick with a marker but most of them don't do that. All of the BME280s we used were like that.

kanazir, 2020-01-26:
There is Q&A section and the seller says just that (screenshot in attachment). Also, if you browse through customer reviews, you'll find the customers complain they received the wrong one (page 7 of reviews). Maybe I am wrong but the seller failed to send me the sensor in 9 days so maybe he is not so reliable.

I ordered the part from [another seller](https://www.aliexpress.com/item/32654011852.html) and will let you know once the sensor arrives.

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

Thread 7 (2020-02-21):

Pictures of Klimerko

misavasic, 2020-02-21:
Hi,
Can someone share pictures of assembly process of Klimerko or at least pictures of final product. I have all parts needed except 3D case but I am not so sure how final assembly should look like.
Thanks in advance

epiller, 2020-02-23:
Sorry about that, I thought the instructions in the README were sufficient.
You'll see the assembled "base" on the photos below, front and back.
I'll get some proper photos and put them in the documentation soon.
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

misavasic, 2020-02-24:
Thanks. Instructions are detailed but as someone said "One Look Is Worth A Thousand Words". My goal is to build it without any soldering if possible. When assembled i will post manual and pictures here.

Closed 2020-02-24.

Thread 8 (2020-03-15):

Small README fix

kanazir, 2020-03-15:
Hi,

on [NodeMCU Preparation](https://github.com/DesconBelgrade/Klimerko#nodemcu-preparation) the README says that PMS7003 sensor should be powered from VIN pin of NodeMCU. But, that pin can't be used to power anything on v3 - VUSB should be used instead.

Can you fix it, please?

epiller, 2020-03-18:
Hey, you most likely have the NodeMCU board with CH340 chip (that's the cheaper one 😄). That board is *off* in many ways, such as being incompatible with breadboards, the VIN issue you're having, the inferior serial-to-usb chip and the incompatibility with the 3D printed enclosure provided in this repo. The one linked in this README is the CP2012-based one, which doesn't have any of these issues.

kanazir, 2020-03-18:
Ah... I had one in my drawer for a long time so, I used it for the project, not thinking about its quality :smiley:
Thanks!

Closed 2020-03-18.

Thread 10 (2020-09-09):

Data from AllThingsTalk not pulled into klimerko.org

bradaric, 2020-09-09:
Data from the device gets sent to allthingstalk.com every 15 minutes, but the map & charts on klimerko.org do not display it correctly (stuck on the same value for all parameters for the last 24h and more).

bradaric, 2020-09-16:
Data on the map got unstuck this morning

Closed 2020-09-16.

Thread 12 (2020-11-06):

Compiling and connecting via Serial Monitor

dcabro, 2020-11-06:
Executable segment sizes:
IROM   : 284884          - code in flash         (default or ICACHE_FLASH_ATTR)
IRAM   : 30608   / 32768 - code in IRAM          (ICACHE_RAM_ATTR, ISRs...)
DATA   : 1492  )         - initialized variables (global, static) in RAM/HEAP
RODATA : 7948  ) / 81920 - constants             (global, static) in RAM/HEAP
BSS    : 31136 )         - zeroed variables      (global, static) in RAM/HEAP
Sketch uses 324932 bytes (31%) of program storage space. Maximum is 1044464 bytes.
Global variables use 40576 bytes (49%) of dynamic memory, leaving 41344 bytes for local variables. Maximum is 81920 bytes.
esptool.py v2.8
Serial port COM3
Connecting........_____....._____....._____....._____....._____....._____.....____Traceback (most recent call last):
  File "C:\Users\Darko\AppData\Local\Arduino15\packages\esp8266\hardware\esp8266\2.7.4/tools/upload.py", line 65, in <module>
    esptool.main(cmdline)
  File "C:/Users/Darko/AppData/Local/Arduino15/packages/esp8266/hardware/esp8266/2.7.4/tools/esptool\esptool.py", line 2890, in main
    esp.connect(args.before)
  File "C:/Users/Darko/AppData/Local/Arduino15/packages/esp8266/hardware/esp8266/2.7.4/tools/esptool\esptool.py", line 483, in connect
    raise FatalError('Failed to connect to %s: %s' % (self.CHIP_NAME, last_error))
esptool.FatalError: Failed to connect to ESP8266: Timed out waiting for packet header
esptool.FatalError: Failed to connect to ESP8266: Timed out waiting for packet header

_
Also Serial monitor shows garbage although baud rate is properly set:

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

dcabro, 2020-11-06:
When pressing reset, Node MCU blinks the blue led once, and serial monitor shows that garbage. All software up to date.

epiller, 2020-11-10:
Are you sure you're using the latest Arduino version, 1.8.13?

dcabro, 2020-11-10:
Yes, 100% sure.
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

epiller, 2020-11-10:
- Do you have any other Serial ports available?
- What does the back of your NodeMCU board say? It should be marked as "Amica"

dcabro, 2020-11-10:
No,only one, COM3
Not sure which is the "back" side, but one side (where the pins are) is white, and has nothing inscribed
Other side, with wifi module on it, has "HW-306" in the middle. Don't see "Amica" anywhere. Here is the pic.

Btw, NodeMCU board was ordered months ago - I followed the link to AE from this project on github (btw it's broken right now). Looking at my order details, the item description was "V3 Wireless module NodeMcu 4M bytes Lua WIFI Internet of Things development board based ESP8266 ESP-12E for arduino CP2102"

dcabro, 2020-11-10:
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

epiller, 2020-11-10:
That's really weird. The board should look exactly like this:
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
and like this on the bottom side
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

It seems like you've received a counterfeit NodeMCU for some reason.
- Try lowering the upload baud rate (Tools > Upload Speed) to 9600 and then try to upload the firmware again.
- The gibberish you're seeing in the Serial monitor is probably intelligible once you match its baud rate, so try scrolling through different baud rates in Serial monitor and see if the text starts making sense at some point (could be 9600 or 57600) and post it here if you get any results.

dcabro, 2020-11-10:
Yeah, mine is different from that bottom side, but like I said, the exact one I ordered was linked to your page...

Anyway, 74880 baud seems to be giving something readable, but it does not progress from here:

 ets Jan  8 2013,rst cause:2, boot mode:(7,2)

epiller, 2020-11-10:
Can you try using 9600 baud rate to upload the firmware onto the device?
If that fails, keep the upload speed at 9600 but disconnect the NodeMCU from your computer, then press and hold the FLASH button on the NodeMCU and then (while holding the button), connect it to your computer and only then release the button, and then try uploading again at the same baud rate.

dcabro, 2020-11-10:
57600 is the lowest speed I have in "upload speed"

epiller, 2020-11-10:
Ah, right, sorry about that. Keep it at 115200 and try the second thing from the previous message.

dcabro, 2020-11-10:
Arduino: 1.8.13 (Windows 10), Board: "NodeMCU 1.0 (ESP-12E Module), 80 MHz, Flash, Legacy (new can return nullptr), All SSL ciphers (most compatible), 4MB (FS:2MB OTA:~1019KB), 2, v2 Lower Memory, Disabled, None, Only Sketch, 115200"

Executable segment sizes:

IROM   : 284884          - code in flash         (default or ICACHE_FLASH_ATTR)

IRAM   : 30608   / 32768 - code in IRAM          (ICACHE_RAM_ATTR, ISRs...)

DATA   : 1492  )         - initialized variables (global, static) in RAM/HEAP

RODATA : 7948  ) / 81920 - constants             (global, static) in RAM/HEAP

BSS    : 31136 )         - zeroed variables      (global, static) in RAM/HEAP

Sketch uses 324932 bytes (31%) of program storage space. Maximum is 1044464 bytes.

Global variables use 40576 bytes (49%) of dynamic memory, leaving 41344 bytes for local variables. Maximum is 81920 bytes.

esptool.py v2.8

Serial port COM3

Connecting........_____....._____....._____....._____....._____....._____.....____Traceback (most recent call last):

  File "C:\Users\darko\AppData\Local\Arduino15\packages\esp8266\hardware\esp8266\2.7.4/tools/upload.py", line 65, in <module>

    esptool.main(cmdline)

  File "C:/Users/darko/AppData/Local/Arduino15/packages/esp8266/hardware/esp8266/2.7.4/tools/esptool\esptool.py", line 2890, in main

    esp.connect(args.before)

  File "C:/Users/darko/AppData/Local/Arduino15/packages/esp8266/hardware/esp8266/2.7.4/tools/esptool\esptool.py", line 483, in connect

    raise FatalError('Failed to connect to %s: %s' % (self.CHIP_NAME, last_error))

esptool.FatalError: Failed to connect to ESP8266: Timed out waiting for packet header

esptool.FatalError: Failed to connect to ESP8266: Timed out waiting for packet header

_

This report would have more information with
"Show verbose output during compilation"
option enabled in File -> Preferences.

dcabro, 2020-11-10:
And the serial console is showing:

```
 ets Jan  8 2013,rst cause:2, boot mode:(7,6)

waiting for host
```

dcabro, 2020-12-03:
bump

dcabro, 2020-12-04:
In most of the cases, it's the STUPID user (that would be me), and not the hardware or the code...

Anyway, I ordered a new node mcu, and when it arrived, before I re-soldered everything, I wanted to make sure that it was okay in the first place. And you know what? PMS7003 RX was soldered do D8 instead of D6. So when I fixed that, everything started working without issues.

So sorry for all the trouble and thank you!

Closed 2020-12-04.

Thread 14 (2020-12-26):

Can't connect to AllThingsTalk

abukva, 2020-12-26:
Since two days ago my Klimerko can't connect to AllThingsTalk in order to deposit data. I've did reconfiguration of all parameters, tried configuring new Token and even tried creating a new device and configuring with that. I've turned on debug mode in `Klimerko_Firmware/src/AllThingsTalk/AllThingsTalk_WiFi.h` line ` [195]   bool debugVerboseEnabled = false; ` to `true` and I see that Klimerko manages to send Firmware version asset and wifi-signal, after that it gets stuck on Connecting to AllThingsTalk...... line.

```
WiFi Signal: Excellent
---------------- HTTP Response from AllThingsTalk (Begin) ----------------
HTTP/1.1 200 OK
Content-Type: application/json; charset=utf-8
Server: Mono-HTTPAPI/1.0
Date: Sat, 26 Dec 2020 09:31:21 GMT
Transfer-Encoding: chunked

1a7
{"deviceId":"MYDEVICEID","thing":null,"id":"rMHJDGjI4NGMa1cPAducjlc4","name":"firmware","title":"Firmware Version","is":"sensor","description":null,"createdOn":"2020-12-05T19:53:06.587Z","updatedOn":"2020-12-26T09:31:21.812Z","createdBy":null,"updatedBy":"rMHJDGjI4NGMa1cPAducjlc4","profile":{"type":"string"},"control":{"name":""},"state":{"at":"2020-12-23T14:00:39.45Z","value":"1.3.0"},"style":"undefined"}
0

----------------- HTTP Response from AllThingsTalk (End) -----------------
---------------- HTTP Response from AllThingsTalk (Begin) ----------------
HTTP/1.1 200 OK
Content-Type: application/json; charset=utf-8
Server: Mono-HTTPAPI/1.0
Date: Sat, 26 Dec 2020 09:31:21 GMT
Transfer-Encoding: chunked

1b3
{"deviceId":"MYDEVICEID","thing":null,"id":"9sXVAxIkZRHecBtmDd95IWMD","name":"wifi-signal","title":"WiFi Signal Strength","is":"sensor","description":null,"createdOn":"2020-12-05T19:53:06.586Z","updatedOn":"2020-12-26T09:31:21.931Z","createdBy":null,"updatedBy":"9sXVAxIkZRHecBtmDd95IWMD","profile":{"type":"string"},"control":{"name":""},"state":{"at":"2020-12-24T07:20:43.289Z","value":"Excellent"},"style":"undefined"}
0

----------------- HTTP Response from AllThingsTalk (End) -----------------
HTTP Connection (for Asset creation) to AllThingsTalk Closed
Connecting to AllThingsTalk...............................................................................................................................
```

epiller, 2020-12-28:
- What model NodeMCU are you using? Please attach a photo along with the wiring.
- What board definition do you have installed? Make sure you're running esp8266 core 2.7.4
- Make **sure** you're using the correct AllThingsTalk Credentials. Check if you're copying the Device ID correctly and make sure you're copying the whole Device Token, including "maker:"
- Check if you're running Arduino IDE 1.8.13

abukva, 2020-12-31:
Hi, it turned at the end that AllThingsTalk randomly blocked my IP, so after restarting my router and acquiring a new IP everything works now.

Closed 2020-12-31.

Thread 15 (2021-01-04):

Klimerko stops working - dots in serial monitor

dcabro, 2021-01-04:
Not sure why it stops working, but I only see dots in serial monitor. This has happened at least 5-10 times so far.

Is there a way to debug this? Or do you know what those dots mean?

epiller, 2021-01-04:
Can you double check your AllThingsTalk credentials? Try generating a new Token if you're sure they're correct.

dcabro, 2021-01-04:
Everything starts working without issues after hard reset (power off/on)

dcabro, 2021-01-09:
So it happened again:
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

dcabro, 2021-01-10:
And again.

epiller, 2021-01-10:
What you're seeing is the device trying to connect to something (the blue LED on the NodeMCU should be fading in/out). I'm assuming you opened Serial Monitor _after_ the device stopped responding and if that's the case, make sure to have Serial Monitor open before this issue happens so you can see exactly what it says before it fails.
Before you do this, I'd recommend changing line **113** `device.debugPort(Serial);` to `device.debugPort(Serial, true);` which will enable verbose debug output from the AllThingsTalk SDK.

dcabro, 2021-01-10:
Correct, I opened the Serial Monitor _after_ the device stopped responding. I've changed the line 113 and will leave the serial monitor open. Will let you know when it stops working again. Thanks.

dcabro, 2021-01-11:
`Asset: wifi-signal, Value: Good
AllThingsTalk Connection Dropped! Reason: Network connection was broken
Connecting to WiFi: darknet.....................................................`

So the wifi connection was dropped. But why doesn't it reconnect?

epiller, 2021-01-12:
Are you running the latest ESP8266 core? If you are, I have no idea what could be causing this as I don't have a way to test it because it works on my end (and seems to work on other people's devices as well).

dcabro, 2021-01-12:
I'm running ESP8266 2.7.4. So do you think it's a hardware issue or a software one? I do have a spare NodeMCU that I can switch to if you think it's a hardware issue.

epiller, 2021-01-12:
It could very well be a software issue, but it's really hard to tell what's up. I'd say go for it and change the board, but before you do that, check your WiFi: Try changing the channel, seeing how many devices are connected to the 2.4GHz network (if it's a dual band router), connecting to a different WiFi, etc.

dcabro, 2021-01-12:
I have other wifi clients (like cell phones) and they are all working fine,
or at least they do not get stuck if they are disconnected.

Furthermore, I don't believe that wifi client that never gets disconnected
from the AP/Router even exists. Instead this probably happens often and its
no big deal as long as they reconnect and continue working.

The real question is which part of the code is responsible for the wifi
connection? I'm gonna ping those devs if that's not you.

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

epiller, 2021-01-19:
Nothing pops in my mind right now except going deep into ESP Arduino Core WiFi classes.

Milutix, 2021-01-24:
Filename: ATT_ESP8266.h
Line: 292

There is a while loop which never ends.
It prints out the '.' character every 10000ms.

I presume you should be trying to reconnect instead?
Line 291 should be placed within this while loop if I understand this correctly.

epiller, 2021-01-25:
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

It does end - once the device reconnects to WiFi but in your case it doesn't.
The sketch you upload to your ESP8266 is not the sole thing that's going to run on it. There's some additional stuff happening in background, one of them being WiFi connection handling (which is the reason why delay(x) for prolonged periods crashes the connection).
Once WiFi.begin is executed, credentials are passed to the underlying WiFi handling functions and the device is given permission to start connecting to WiFi. If it ever disconnects, it should automatically try to reconnect again, but this is invisible to the user.
I will look into this in more detail, try to replicate the issue on my Klimerko and figure out a fix.
@dcabro I saw that thread sometime last year but I'll have to look at it again. Thanks!

dcabro, 2021-02-09:
Pulled the device out of use.

epiller, 2021-12-15:
Hey @dcabro, the new [2.0.0 release](https://github.com/DesconBelgrade/Klimerko/releases/tag/2.0.0) may fix this issue.

Closed 2021-02-09.

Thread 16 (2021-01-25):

Not visable on the map

nexbg, 2021-01-25:
Hi, friend of mine and myself  assembled 1 measuring station. Everything has been set and we can see that station is up and running, measuring, and it is "shared" via AllThingsTalk .

However, we can not see it on "Vazduh gradjanima" page, even we have location set up.

Do you know what could be a problem?

epiller, 2021-01-26:
That's odd. Could you send me the Device ID of your Klimerko?

nexbg, 2021-01-26:
7b7a5oXyJeO9JCk8r7jXGeG8

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

epiller, 2021-02-01:
Fixed!

Closed 2021-02-01.

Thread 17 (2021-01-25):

Bridge connector for PMS7003

nexbg, 2021-01-25:
Hi,

in the package we have ordered we have not received bridge connector with cables. Is there any suggestion from your end for alternative solution?

For a test purpose we have soldered wires to pines directly (we have found scheme on internet), but it is not the best solution since wires can be moved and even run into short circuit.

Thank you in advance.

epiller, 2021-01-25:
[I found this on AliExpress](https://www.aliexpress.com/item/32780006665.html), but the shipping prices are awful.
If you can't order from AliExpress, try buying another PMS7003 from somewhere else and ask the seller to provide you with more "G7 Adapters" (bridge board).
The first time I played with PMS7003 I also forgot the bridge board and did the same thing as you - soldered it by hand. It still holds to this day, but you should definitely avoid that as a solution.

Closed 2021-01-25.

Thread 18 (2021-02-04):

Using batery

nexbg, 2021-02-04:
Hi everyone,

Did anyone used autonomous energy source like battery to supply station with power. I do not have electricity source outside, and trying to find way to make it easy.

BR,
Nemanja

epiller, 2021-02-04:
Hey, due to the linear power regulation circuit on the NodeMCU and the fact that PMS7003 requires 5V to operate (because of the fan), efficient battery powered operation isn't something that could be done well without creating a custom circuit board. What I suggest is that you use a power bank, but don't expect long runtime - I'd guesstimate around 2-3 days.

batica81, 2021-02-04:
Depends on the bank of course. I tried with a small one with two 18650
cells and that lasted about one day.

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

nexbg, 2021-02-04:
Thanks!
So, power bank with solar panel can be good solution actually. :)

On Thu, Feb 4, 2021 at 1:01 PM Vojislav Ristivojevic <
notifications@github.com> wrote:

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

--
Nemanja Stamencic PMP
Cell: +381641570067
Mail: nemanja.stamencic@gmail.com
Web: www.stamencic.net
Twitter: @stamencic
Ln: http://rs.linkedin.com/in/nemanjastamencic

epiller, 2021-02-04:
Thanks for the input @batica81. I would also like to add that the firmware isn't optimized for battery powered operation, in a sense that NodeMCU isn't going into low-power state at all. This could be implemented but would require a whole bunch of changes, a lot of testing and a hardware change (two pins on the NodeMCU would need to be connected to each other in order to enable waking up from deep sleep).

Closed 2021-02-07.

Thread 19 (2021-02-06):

Verification process

drnetcoding, 2021-02-06:
Hi everyone,

I am interested in the verification process. I couldn't find out how to do it. Also assume that only verified devices can be found in the AirCare application as well?

And another question:
If we share data with the other two communities, where can find the values from the device?

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

Thanks,
Dusan

CorvusCoraxHD, 2021-03-17:
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

Hey @drnetcoding ,

To add your Klimerko sensor to the **AirCare** app, you need to add it to "Vazduh gradjanima" public grounds and contact the AirCare dev by email, send him the device ID and ask him to add it to the app. He's very quick to respond and act, so your sensor should become visible in the app within an hour.

This is a first-hand experience, as I went through this process a few days ago.

Have a great day,
CC

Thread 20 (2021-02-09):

Remove station from the map

dcabro, 2021-02-09:
How do you do it?

epiller, 2021-02-09:
It should be automatically removed shortly after you stop sharing with Vazduh gradjanima ground on AllThingsTalk

Closed 2021-02-18.

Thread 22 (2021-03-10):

System Error: Air Quality Sensor (PMS7003) returned no data on data request this time.

y0d4a, 2021-03-10:
Zdravo,

imam problem sa dobijanjem data sa senzora za vazduh.
Tacnije error koji dobijam je "System Error: Air Quality Sensor (PMS7003) returned no data on data request this time."
Ono sto sam uspeo da vidim, jeste da VIN na nodemcu daje 1.6V, a sam senzor je 5V.
Sta mogu da uradim da resim ovaj prob.?

hvala

milcha, 2021-03-11:
Ja sam imao isti problem i samo sam zicu sa VIN-a zalemio na jedan od 3.3V i sad radi bez problema....

Pozdav

y0d4a, 2021-03-11:
to i meni pade na pamet, al` reko bolje da pitam, i videh da je senzor na 5V, pa reko dal` ce biti dovoljno...
Ok, probacu, hvala!

epiller, 2021-03-11:
Izgleda da ste kupili pogresan NodeMCU (sa CHG340 cipom) jer je bio jeftiniji par centi 😄
PMS7003 Senzor zahtjeva 5V, tako da ga spojite na "5V" pin na NodeMCU (ako nema tog pina, posaljite sliku ovdje).
Senzor na 3v3 djeluje kao da radi jer salje podatke, ali zapravo 5V koristi za ventilator u sebi tako da vrijednosti koje daje nisu tacne jer vazduh ne cirkulise.

y0d4a, 2021-03-11:
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

taj je model.. da budem iskren, nisam ni gledao da je tacan moden :/
po slici za ovaj model, izgleda da moze na VV ?
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

epiller, 2021-03-11:
Da, moze na VV pin

y0d4a, 2021-03-11:
Air Quality is Very Polluted (Average: Very Polluted)
PM 1:          75 (Average: 75)
PM 2.5:        116 (Average: 116)
PM 10:         124 (Average: 124)
Temperature:   21.0 (Average: 21)
Humidity:      34.8 (Average: 34)
Pressure:      1006 (Average: 1006)

hvala na pomoci!

Closed 2021-03-11.

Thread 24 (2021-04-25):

Error while uploading the sketch on MacOS Big Sur

selkuncik, 2021-04-25:
I followed your instructions for firmware upload but got an error when I tried to upload the firmware. Didn't copy whole output but main line was "pyserial or esptool directories not found next to this upload.py tool."
I googled it and found a thread in Arduino forum with this fix: https://forum.arduino.cc/t/pyserial-and-esptools-directory-error/671804/5
I don't understand anything that is done there, but I made the change to the file and it worked! So I thought it worth mentioning, maybe you can add it to the manual for future users.
Cheers for great project!

epiller, 2021-05-20:
Great find! It appears to be one of many things Big Sur broke... If you're not using Arduino for anything else besides Klimerko, could you try the newest version (1.8.15) and see if that solves the issue without the file modification?

Closed 2021-10-08.

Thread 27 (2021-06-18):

Selling an assembled Klimerko device

mayeaux, 2021-06-18:
Hi there. I'd like to participate with my own Klimerko device but I don't really have the capacity (really time) to take on assembling my own device. Given that a proprietary air pollution sensor can cost hundreds of dollars, would someone be able to assemble and sell me a working Klimerko device that I can hook up to the cloud myself? Thanks!

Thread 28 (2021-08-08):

Podrska za HomeAssistant API

stefancvetkovic, 2021-08-08:
Pozdrav,
Mozda bi mogli da napravimo jednu custom integraciju ili integraciju od strane HomeAssistant zajednice (ukoliko je odobre) da se izlozi API koji bi se integrisao sa HomeAssistant-om.

Pozdrav..

CorvusCoraxHD, 2021-08-08:
Podržavam. I meni to izgleda kao izuzetno korisno.

ipantovic, 2021-08-25:
+1

epiller, 2021-10-08:
+10

pedjas, 2022-10-30:
+1

Nešto sam gledo, moglo bi da se uradi obrnuto: da se u Klimerka učita ASPHome firmver koji bi omogućio lak pristup senzorima i povezivanje na Home Assistant, a ne ;ini se da bi bilo komplikovanoda sam Klimerko sa takvim firmerom i dalje šalje podatke i direktno na Klimerko sajt.

ASPHome ima mogućnsot da nod šalje http post i get upite gde treba, što bi trebalo da je dovoljno.

Još nemam Klimerka pa ne mogu da isprobam.

stefancvetkovic, 2022-11-01:
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

Mislis na esphome platformu?
https://esphome.io/

pedjas, 2022-11-01:
> Mislis na esphome platformu? https://esphome.io/

Da.

Nešto sam eksperimentisao danas, bez problema sam namestio da ES8266 modul koji je na EPSHome šalje podatke paralelno i na udaljeni web servis na Internetu (ne Kimerko, nisam gledao kakav je njegov API, nego sam napravio neki improvizovani koji prima HTTP post sa json strukturom u telu).

pedjas, 2022-11-01:
Hmm, nesto ne mogu da nadjem API dokumentaciju za Klimerko sajt.

neorrk, 2022-11-17:
+1

pedjas, 2022-11-17:
Odustao sam od Klimerka. Vidim da je serer sa podacima zatvorenog tipa, nije moguce preuzimati pdoatke, pa cak ne moze covek ni da podeli link na odredjenu mernu stanicu.

Ne vidim svrhu baktati se sa tim. Napravio sam da se podaci šalju na drugu stranu, gde su lako dostupni. Čak i ne mora da se pravi custom fimver, sve se lako uradi u ESPHome.

stefancvetkovic, 2022-11-17:
> Odustao sam od Klimerka. Vidim da je serer sa podacima zatvorenog tipa, nije moguce preuzimati pdoatke, pa cak ne moze covek ni da podeli link na odredjenu mernu stanicu.
>
> Ne vidim svrhu baktati se sa tim. Napravio sam da se podaci šalju na drugu stranu, gde su lako dostupni. Čak i ne mora da se pravi custom fimver, sve se lako uradi u ESPHome.

Koju si integraciju izabrao? openWeather ili nesto drugo?

pedjas, 2022-11-17:
Trenutno sam testirao da šaljem na svoju custom lokaciju, za probu, a još nisam odlučio na koje ću open servise da šaljem.

epiller, 2022-11-17:
[Klimerko.org](https://klimerko.org) vuče podatke sa [AllThingsTalk Maker](https://maker.allthingstalk.com) ground-a "[Vazduh gradjanima](https://maker.allthingstalk.com/ground/3s61Mf0HvqudWXXjv2QzUCnq/devices)", tako da je moguće koristiti ovaj [API poziv](https://api.allthingstalk.io/swagger/ui/index#operation/Devices_GetDevice) kako bi se dobili podaci odredjenog uredjaja.
Što se tiče lokalnog pristupa, moguće je dodati funkcionalnost da Klimerko otvara endpoint na samom uredjaju koji vraća trenutnu vrijednost PM1, PM2.5, PM10, temperaturu, vlaznost, ili pritisak na lokalnoj mreži pa ga onda dodati kao [RESTful Sensor](https://www.home-assistant.io/integrations/sensor.rest/) na HomeAssistant platformi.

pedjas, 2022-11-17:
Ja sam uradio obrnuto. Uređjaj očita senzore i to prosledi u Home Asistant a istovremeno pošalje i http-om na remote lokaciju.
Nema nekog smisla da šaljem podatke negde na Internet pada ih onda odatle dovlačim nazad.

epiller, 2022-11-17:
Ovo za API sam spomenuo u slučaju da hoćeš da prikažeš podatke sa tudjeg senzora u svojoj HomeAssistant instanci.

pedjas, 2022-11-17:
> Ovo za API sam spomenuo u slučaju da hoćeš da prikažeš podatke sa tudjeg senzora (npr. u blizini) u svojoj HomeAssistant instanci.

A da, to bi bilo dobro. Ima jedan Klimerko u blizini pa ću probati sa njim. Kako da saznam ID senzora? Na Klimerko sajtu tog podatka nema.

Bilo bi dobro i da se napravi integracija za Home Assistant tako da se u HA prosto doda uređaj i u konfiguraciji upiše ID na AllThingsTalk i da se dobiju podaci. Da ne mora ručno da se parsira.

epiller, 2022-11-17:
Probaj ga preko imena naći na AllThingsTalk Maker-u, i tamo onda možeš vidjeti ID.
Slažem se da bi bilo dobro ali ne znam ko bi to odradio 😕

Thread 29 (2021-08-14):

Exception problem

saidkg, 2021-08-14:
Zdravo,

dobijam exception i restart odmah po kačenju na wifi.
Exception (0):
epc1=0x40206b9e epc2=0x00000000 epc3=0x40101a31 excvaddr=0x00000000 depc=0x00000000

>>>stack>>>

ctx: cont
sp: 3ffffcb0 end: 3fffffc0 offset: 0190
3ffffe40:  3fff01f4 3fff018c 3fff1304 40206b9e
3ffffe50:  00000000 003f003f 00000000 00000000
3ffffe60:  003f003f 00000000 00000000 0036003f
3ffffe70:  00000000 00000000 002b002f 00000000
3ffffe80:  00000000 0024002f 00000000 4020b630
3ffffe90:  3ffe960e 3fff018c 3ffffed0 4020b661
3ffffea0:  402096d0 3ffffed0 3ffffed0 402032f8
3ffffeb0:  00000000 0000746e 00000000 40203094
3ffffec0:  3ffe9909 3fff145c 3fff018c 40203c98
3ffffed0:  3fff01e8 3fff01dc 3fff01d0 00000002
3ffffee0:  3ffe9909 3fff018c 3fff11c0 3ffe92cf
3ffffef0:  3fff11c0 3fff0f8c 3fff018c 40206d00
3fffff00:  3fff018c 0000676e 4020f644 40206648
3fffff10:  00000000 0000726f 00000000 00000000
3fffff20:  0014001f 00000000 00000000 000b000f
3fffff30:  00000000 3fff018c 3fffff78 4020b421
3fffff40:  3ffe9909 3fff018c 3fff14a0 4020230c
3fffff50:  00000040 00000000 feefeffe feefeffe
3fffff60:  00000000 6c00676e 00000000 00000000
3fffff70:  fe00726f 00000000 00000000 0010001f
3fffff80:  00000000 00000000 65726177 00000000
3fffff90:  feefeffe feefeffe feefeffe 3fff15e4
3fffffa0:  3fffdad0 00000000 3fff15d0 4020bfe0
3fffffb0:  feefeffe feefeffe 3ffe86a0 401014dd
<<<stack<<<

Dekodirano (valjda) u ovo
Exception 0: Illegal instruction
PC: 0x40206b9e
EXCVADDR: 0x00000000

Decoding stack results
0x4020b630: Stream::SendGenericRegular(Print*, int, unsigned int) at C:\Users\saidk\AppData\Local\Arduino15\packages\esp8266\hardware\esp8266\3.0.2\cores\esp8266\StreamSend.cpp line 257
0x4020b661: Stream::SendGenericRegular(Print*, int, unsigned int) at C:\Users\saidk\AppData\Local\Arduino15\packages\esp8266\hardware\esp8266\3.0.2\cores\esp8266\StreamSend.cpp line 267
0x402096d0: SPIClass::setFrequency(unsigned int) at C:\Users\saidk\AppData\Local\Arduino15\packages\esp8266\hardware\esp8266\3.0.2\libraries\SPI\SPI.cpp line 274
0x402032f8: Device::send(CborPayload&) at C:\Users\saidk\Downloads\Klimerko-master\Klimerko_Firmware\src\AllThingsTalk/ATT_ESP8266.h line 864
0x40203094: ArduinoJson6114_000001::DynamicStringWriter ::write(unsigned char const*, unsigned int) at C:\Users\saidk\Downloads\Klimerko-master\Klimerko_Firmware\src\AllThingsTalk\ArduinoJson\Serialization/DynamicStringWriter.hpp line 40
0x40203c98: Device::debugVerbose (double, char) at C:\Users\saidk\Downloads\Klimerko-master\Klimerko_Firmware\src\AllThingsTalk/ATT_ESP8266.h line 50
0x40206d00: Device::createAssets() at C:\Users\saidk\Downloads\Klimerko-master\Klimerko_Firmware\src\AllThingsTalk/ATT_ESP8266.h line 421
0x4020f644: DhcpServer::end() at C:\Users\saidk\AppData\Local\Arduino15\packages\esp8266\hardware\esp8266\3.0.2\cores\esp8266\LwipDhcpServer.cpp line 1098
0x40206648: Device::mqttCallback(char*, unsigned char*, unsigned int) at C:\Users\saidk\Downloads\Klimerko-master\Klimerko_Firmware\src\AllThingsTalk/ATT_ESP8266.h line 757
0x4020b421: Stream::findUntil(char const*, unsigned int, char const*, unsigned int) at C:\Users\saidk\AppData\Local\Arduino15\packages\esp8266\hardware\esp8266\3.0.2\cores\esp8266\Stream.cpp line 107
0x4020bfe0: operator+(char const*, String const&) at C:\Users\saidk\AppData\Local\Arduino15\packages\esp8266\hardware\esp8266\3.0.2\cores\esp8266/WString.h line 295
0x401014dd: calloc(size_t, size_t) at C:\Users\saidk\AppData\Local\Arduino15\packages\esp8266\hardware\esp8266\3.0.2\cores\esp8266\umm_malloc\umm_malloc.cpp line 1181

saidkg, 2021-08-15:
My bad! It appears I used the wrong board definition...
https://github.com/DesconBelgrade/Klimerko/issues/24#issuecomment-845539105

epiller, 2021-12-15:
Hey @saidkg, just wanted to notify you the issue is resolved with the [newest 2.0.0 release](https://github.com/DesconBelgrade/Klimerko/releases/tag/2.0.0)

Closed 2021-08-15.

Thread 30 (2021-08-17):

Upload error

TheLazarus89, 2021-08-17:
Arduino: 1.8.15 (Windows 10), Board: "NodeMCU 1.0 (ESP-12E Module), 80 MHz, Flash, Disabled (new aborts on oom), Disabled, All SSL ciphers (most compatible), 32KB cache + 32KB IRAM (balanced), Use pgm_read macros for IRAM/PROGMEM, 4MB (FS:2MB OTA:~1019KB), 2, v2 Lower Memory, Disabled, None, Only Sketch, 115200"

remove core\core.a: The process cannot access the file because it is being used by another process.

Error compiling for board NodeMCU 1.0 (ESP-12E Module).

Executable segment sizes:

ICACHE : 32768           - flash instruction cache

IROM   : 287860          - code in flash         (default or ICACHE_FLASH_ATTR)

IRAM   : 30525   / 32768 - code in IRAM          (IRAM_ATTR, ISRs...)

DATA   : 1696  )         - initialized variables (global, static) in RAM/HEAP

RODATA : 7628  ) / 81920 - constants             (global, static) in RAM/HEAP

BSS    : 31440 )         - zeroed variables      (global, static) in RAM/HEAP

Sketch uses 327709 bytes (31%) of program storage space. Maximum is 1044464 bytes.

Global variables use 40764 bytes (49%) of dynamic memory, leaving 41156 bytes for local variables. Maximum is 81920 bytes.

esptool.py v3.0

Serial port COM1

Connecting........_____....._____....._____....._____....._____....._____.....____Traceback (most recent call last):

  File "C:\Users\Milisavljevic\AppData\Local\Arduino15\packages\esp8266\hardware\esp8266\3.0.2/tools/upload.py", line 66, in <module>

    esptool.main(cmdline)

  File "C:/Users/Milisavljevic/AppData/Local/Arduino15/packages/esp8266/hardware/esp8266/3.0.2/tools/esptool\esptool.py", line 3552, in main

    esp.connect(args.before, args.connect_attempts)

  File "C:/Users/Milisavljevic/AppData/Local/Arduino15/packages/esp8266/hardware/esp8266/3.0.2/tools/esptool\esptool.py", line 529, in connect

    raise FatalError('Failed to connect to %s: %s' % (self.CHIP_NAME, last_error))

esptool.FatalError: Failed to connect to ESP8266: Timed out waiting for packet header

_

the selected serial port _

 does not exist or your board is not connected

This report would have more information with
"Show verbose output during compilation"
option enabled in File -> Preferences.

[https://prnt.sc/1q6laso]

Does someone know what is the problem?

epiller, 2021-12-15:
Closing this issue

Closed 2021-12-15.

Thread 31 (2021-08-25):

data over LoraWAN capability

ipantovic, 2021-08-25:
short short version:
it would be great if it could report the same over longer distance, backyard, roof, tree or in field.

longer (or if above does not make sense):
Wifi connectivity is great if used in enclosed and in proximity to AP deployments.
Real benefit would be expanding it to talk to LoraWAN gateways and use deep sleep and battery with a possible solar recharge capability.

But one step at the time.
Can we think about extending the communication range by adapting it to support communication trough Lora?

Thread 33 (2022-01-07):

Bme280 merenje temperature.

Buljubasa, 2022-01-07:
Primetio sam da klimerko pokazuje dosta nizu temperaturu od onog napravljenog sa SHT11 koji sam stavio odmah pored.
Vidim da je programski stavljeno da pokazuje 4C manje od vrednosti koju sam BME280 salje.
BME280 hoce da salje nesto vise vrednosti ali to je obicno 0.5-1C, bar su neka moja iskustva takva ili ste imali module sa vecom greskom?

epiller, 2022-01-12:
It's because the heat of the ESP8266 affects the sensor when it's in the 3D printed enclosure as well, [as stated in the firmware source here](https://github.com/DesconBelgrade/Klimerko/blob/cc9c3eb44948a695143bd9019689350339979e3d/Klimerko_Firmware/Klimerko_Firmware.ino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)

Closed 2022-01-12.

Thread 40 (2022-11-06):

Issues with klimerko.org site

ilic5000, 2022-11-06:
I've found a couple of issues/bugs with the klimerko.org site:

1. There is no valid SSL certificate for parts of the site (at least for me in the newest Firefox) and the browser keeps reminding me that the connection is not secure - this should be an easy fix
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

2. On the map there are only PM10 values visible, for PM2.5 you need to click on each of the stations to get a more detailed view. It would be beneficial if there were some switches on the map viewer where you can choose PM10, PM2.5, temperature, humidity, etc. to be shown in the circles on the map for each station. In the current state, UX is really not that great, because you are losing a lot of time trying to find out what you want. For example, if you want to find out PM2.5 values in some specific city,  you will need manually to go to each individual station and click for more details, and then look for PM2.5 values. This could be avoided if there was a way to have PM2.5 values in the circles on the map when you are scrolling/searching through
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

3. Data on the left panel are maybe not be needed, or at least, some sort of header for that table or explanation of what they are would be nice. Maybe it would be better if this panel is hidden by default, with an option to expand the panel
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

4. There is a bug when you open/click on one of the stations, and then close it. Instead of returning you to the point in the map where you've been, you are redirected back to Belgrade (see attached .gif for an example)

Bug reproduced:
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
[better quality](https://imgur.com/a/SDJVwQH)

vultureEmb, 2022-11-23:
Dodao bih da se sajtu teško pristupa u odnosu na bilo koji drugi sajt.

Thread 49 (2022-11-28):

D ali je moguće da se napravi novi model poklopca za Klimerko, zgodniji za 3d štampu?

pedjas, 2022-11-28:
Ovaj model poklopca https://github.com/DesconBelgrade/Klimerko/blob/master/Klimerko_Printable_Case/Housing/Cover.STL ima veliko zaobljenje. To ej tečko lepo odštampati na kućnnim 3d štampačima.

Može li da se napravi verzija koja ima umerenije zaobljenje, reda poluprečnika od 3 - 4 milimetra?

ravenns, 2024-09-08:
Koji stampac koristis? Da li si probao da promenis part fan da jace duva/bolje hladi?

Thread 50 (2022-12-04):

Problem tokom povezivanja na Wifi...

vultureEmb, 2022-12-04:
Pozdrav,

Spustio sam firmware preko Arduino IDE 2.0.2 (OS Windows 7) verzije na NodeMCU sa CP2102 i dobijam ovu gresku u Serial Monitoru:

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

Da li je neko imao slican problem?

Closed 2022-12-04.

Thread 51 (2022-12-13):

Documenting MQTT messages

jrocketfingers, 2022-12-13:
Hi folks, I'm running a Klimerko-like setup (same sensors, same NodeMCU, but possibly ESP32 instead), with ESPHome firmware. **If I understand Klimerko's code correctly**, it's just sending MQTT messages to `api.allthingstalk.io`, and klimerko.org is picking up Klimerko devices from there? If this is the case, I could contribute sensor data as well if I knew the messages being sent.

I should be able to deduce MQTT messages from the codebase, but are there any intentions to document this? If not, I'd be glad to document them if I manage to make it work. In that case, could you direct me on how/where would you want it documented?

jrocketfingers, 2022-12-13:
Just read this off a Klimerko unit UART logs, pasting it here for future reference:
```json
{"air-quality":{"value":"Good"},"pm1":{"value":16},"pm2-5":{"value":22},"pm10":{"value":24},"temperature":{"value":19.59},"humidity":{"value":26.51},"pressure":{"value":1003.7},"firmware":{"value":"2.0.0"},"wifi-signal":{"value":"Good"}}
```

epiller, 2022-12-20:
Hey @jrocketfingers, Klimerko follows the [AllThingsTalk MQTT topic/payload convention documented here](https://docs.allthingstalk.com/developers/api/messaging/).

jrocketfingers, 2022-12-21:
Hey @epiller, thanks! I've seen that doc, but it seems to explain the per-asset messages, not the bulk transfer that Klimerko seems to be making. I assume you've actually used [these device states documented on the data formats page](https://docs.allthingstalk.com/developers/data-formats/#device-states)?

epiller, 2022-12-28:
@jrocketfingers Yup! That's exactly what's being used.

dkwireless, 2023-12-18:
Can you please share config yaml so we dont have to do it all ove again? :)

dkwireless, 2023-12-19:
No problem. Thanks. I'm still waiting on parts. Just ordered them. But will write here if I manage to build something.

dkwireless, 2024-03-01:
Sucess!
Thanks @jrocketfingers for pointing me in right direction.

You can find code on https://github.com/dkwireless/ESPHOME-Klimerko

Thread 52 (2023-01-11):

Klimerko Website Repo

igorradovanov, 2023-01-11:
Hello,
Is there a GitHub repository for the klimerko.org website? I believe it would be beneficial to open it up to the community for them to submit pull requests to fix any bugs found in the reported issues. Thank you.

ilic5000, 2023-01-12:
I was going to suggest this as well. 👍 But maybe they are not maintaining or developing website anymore, I didn't get any responses in this issue regarding some things that I've come across on the website
https://github.com/DesconBelgrade/Klimerko/issues/40

epiller, 2023-01-13:
We're aware of the issues with the current website and a complete redesign is currently in the works!

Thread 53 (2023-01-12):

Klimerko FW is not compiling

ilic5000, 2023-01-12:
I had a problem when compiling FW - Arduino IDE said that the result is missing (nothing is returned) when "(!wifiConnectionLost)" is false. I've fixed this issue by returning "Error" for that case, without it it wouldn't work.

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

https://github.com/DesconBelgrade/Klimerko/blob/master/Klimerko_Firmware/Klimerko_Firmware.ino#L790-L809

epiller, 2023-01-13:
I've just installed Arduino IDE 2.0.3 in order to try and replicate this issue but it compiled without any issues. I'll fix that function anyways.

epiller, 2023-01-13:
Fixed in [Firmware v2.1.1](https://github.com/DesconBelgrade/Klimerko/releases/tag/2.1.1).

Closed 2023-01-13.

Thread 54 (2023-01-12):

Readme update needed - communication with NodeMCU on Windows10 needs a driver

ilic5000, 2023-01-12:
When I connected NodeMCU to my PC, Windows could not automatically install the required drivers and because of that device was not recognized (in the device manager it had a yellow icon and it said that drivers were not installed). After a quick search I've found this site:

https://www.silabs.com/developers/usb-to-uart-bridge-vcp-drivers?tab=downloads

And after installing [CP210x Universal Windows Driver](https://www.silabs.com/documents/public/software/CP210x_Universal_Windows_Driver.zip), everything worked perfectly. I got a new COM port  (COM4) as an option in Arduino IDE, it had only COM1 before the installation of drivers, and it did not work with that COM1.

It would be a good idea to add this in the Troubleshooting section of the main Readme.

epiller, 2023-01-13:
- Link to CP2102 Windows driver added in [Software](https://github.com/DesconBelgrade/Klimerko#software) section of README. (271eb5a10059baa00250a45d28f8b2115a17c3f3)
- COM port ambiguity mentioned in [Uploading Firmware](https://github.com/DesconBelgrade/Klimerko#uploading-firmware) and [Updating Using Arduino IDE](https://github.com/DesconBelgrade/Klimerko#updating-using-arduino-ide) section of README. (e8887f4a5fb94abd6acefcb0480442c1946dc960)

Closed 2023-01-13.

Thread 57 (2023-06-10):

Integrating with Home Assistant

DjordjeMandic, 2023-06-10:
Just a suggestion, when its already on the network mdns discovery should be implemented and home asstiant integration made for it.

rajkoc, 2024-01-03:
+1

Polimac, 2024-01-26:
+1

psyhomb, 2024-03-10:
You can use existing [RESTful](https://www.home-assistant.io/integrations/sensor.rest) integration to add PM sensors in Home Assistant.

Example:

```yaml
- name: Klimerko PM2.5
  unique_id: klimerko_pm2_5
  platform: rest
  resource: https://api.allthingstalk.io/asset/<ASSET_ID>
  headers:
    Authorization: !secret att_maker_api_token
    Content-Type: application/json
  device_class: pm25
  icon: mdi:molecule
  json_attributes_path: "$.state"
  json_attributes:
    - at
  value_template: "{{ value_json.state.value }}"
```

rajkoc, 2024-03-11:
Has it worked for anyone?

psyhomb, 2024-03-11:
It is working for me.  🙂
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

rajkoc, 2024-03-11:
Solved, it works. In the authorization line, add Bearer and then token.

psyhomb, 2024-03-11:
In my case `Bearer` is part of the secret.

`config/secrets.yaml`
```yaml
att_maker_api_token: "Bearer maker:<TOKEN>"
```

psyhomb, 2024-03-13:
I have also created a more comprehensive configuration that will create and collect data from all Klimerko sensors (PM1, PM2.5, PM10, Temperature, Humidity and Atmospheric Pressure) all in one API call.

You only need to replace `<DEVICE_ID` with real value and to update secret per [this](https://github.com/DesconBelgrade/Klimerko/issues/57#issuecomment-1988473141) post.

```yaml
rest:
  # Klimerko
  - resource: https://api.allthingstalk.io/device/<DEVICE_ID>
    method: GET
    headers:
      Authorization: !secret att_maker_api_token
      Content-Type: application/json
    scan_interval: 60
    sensor:
      # PM1 sensor
      - name: Klimerko PM1
        unique_id: klimerko_pm1
        device_class: pm1
        unit_of_measurement: "µg/m³"
        icon: mdi:molecule
        json_attributes_path: "$.assets[?(@.name=='pm1')].state"
        json_attributes:
          - at
        value_template: |
          {% set sensor = value_json.assets | selectattr("name", "eq", "pm1") | first | default %}
          {{- sensor.state.value }}
      # PM2.5 sensor
      - name: Klimerko PM2.5
        unique_id: klimerko_pm2_5
        device_class: pm25
        unit_of_measurement: "µg/m³"
        icon: mdi:molecule
        json_attributes_path: "$.assets[?(@.name=='pm2-5')].state"
        json_attributes:
          - at
        value_template: |
          {% set sensor = value_json.assets | selectattr("name", "eq", "pm2-5") | first | default %}
          {{- sensor.state.value }}
      # PM10 sensor
      - name: Klimerko PM10
        unique_id: klimerko_pm10
        device_class: pm10
        unit_of_measurement: "µg/m³"
        icon: mdi:molecule
        json_attributes_path: "$.assets[?(@.name=='pm10')].state"
        json_attributes:
          - at
        value_template: |
          {% set sensor = value_json.assets | selectattr("name", "eq", "pm10") | first | default %}
          {{- sensor.state.value }}
      # Temperature sensor
      - name: Klimerko Temperature
        unique_id: klimerko_temperature
        device_class: temperature
        unit_of_measurement: "°C"
        icon: mdi:thermometer
        json_attributes_path: "$.assets[?(@.name=='temperature')].state"
        json_attributes:
          - at
        value_template: |
          {% set sensor = value_json.assets | selectattr("name", "eq", "temperature") | first | default %}
          {{- sensor.state.value }}
      # Humidity sensor
      - name: Klimerko Humidity
        unique_id: klimerko_humidity
        device_class: humidity
        unit_of_measurement: "%"
        icon: mdi:water-percent
        json_attributes_path: "$.assets[?(@.name=='humidity')].state"
        json_attributes:
          - at
        value_template: |
          {% set sensor = value_json.assets | selectattr("name", "eq", "humidity") | first | default %}
          {{- sensor.state.value }}
      # Atmospheric Pressure sensor
      - name: Klimerko Atmospheric Pressure
        unique_id: klimerko_atmospheric_pressure
        device_class: atmospheric_pressure
        unit_of_measurement: "mbar"
        icon: mdi:gauge
        json_attributes_path: "$.assets[?(@.name=='pressure')].state"
        json_attributes:
          - at
        value_template: |
          {% set sensor = value_json.assets | selectattr("name", "eq", "pressure") | first | default %}
          {{- sensor.state.value }}
```

rajkoc, 2024-03-13:
Thank you very much Miloš. Works great!

DjordjeMandic, 2024-03-13:
This works fine when it has internet access. It's still not a solution to the problem.

IMO Klimerko should have local integration with home assistant, whole point of smart home is that it works without internet access too.

psyhomb, 2024-03-13:
> This works fine when it has internet access. It's still not a solution to the problem.
>
> IMO Klimerko should have local integration with home assistant, whole point of smart home is that it works without internet access too.

I couldn't agree more, still at this very moment this is all we got.

Also Klimerko firmware is using pub/sub model (MQTT protocol), thus sensor data are pushed to public broker's endpoint, so one way on how you can generate local data is by provisioning a local broker (e.g. [Mosquitto](https://github.com/home-assistant/addons/blob/master/mosquitto/DOCS.md)) and by modifying Klimerko source code and [default broker endpoint](https://github.com/DesconBelgrade/Klimerko/blob/master/Klimerko_Firmware/Klimerko_Firmware.ino#L51) to use local broker address.
I know, this way you are losing public endpoint but this is just another proposal that you can implement in almost no time...

DjordjeMandic, 2024-03-14:
> So isn't the point of sharing with the community?

It is, my intention was never to move it to local only. My intention is to have it do its job like it is now and besides that publish data to HA also.

My idea was to expose sensors to HA directly via HA API or use one more MQTT connection.

If anyone is willing to contribute we can implement the following:
  - MDNS local discovery (useful for HA integration)
  - Local REST API for direct connections (useful for HA integration)
  - One more MQTT connection server where HA is connected which impelments MQTT Discovery to expose sensors

Exposed stuff would include:
  - All sensor data which is already published
  - Current WiFi status (more detailed)

psyhomb, 2024-03-14:
One advantage of [this](https://github.com/DesconBelgrade/Klimerko/issues/57#issuecomment-1994309780) approach is that you can basically add any device that is registered and shared on the AllThingsTalk platform to HomeAssistant, not only devices that you own.
You just need to pick a shared <DEVICE_ID> from the Vazduh Gradjanima joined ground and to use ground token instead of device token (personal).
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

psyhomb, 2024-03-14:
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

It would be great to have all these features implemented, the only concern I have, not saying it's justifiable, is that I don't know if this hardware (ESP8266 board) have sufficient amount of resources to support all that and how well and reliable it will work.
This is more of a question then concern, because I really don't have any extended knowledge nor experience with this hardware.

DjordjeMandic, 2024-03-15:
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

RAM is limit here. ArduinoJson will be biggest issue but it all can be managed with proper memory allocation and code layout to prevent fragmentation as much as possible.

Rest can be managed with freertos (should have been from the start imo when there is multiple services running).

psyhomb, 2024-03-15:
@DjordjeMandic thank you for detailed explanation.

psyhomb, 2024-10-06:
If anyone is interested, I’ve also created a [mini-graph-card](https://github.com/kalkih/mini-graph-card) that can be used with Klimerko [entities](https://github.com/DesconBelgrade/Klimerko/issues/57#issuecomment-1994309780).

```yaml
type: vertical-stack
cards:
  - type: custom:mini-graph-card
    name: Outdoor
    entities:
      - entity: sensor.klimerko_temperature
        name: Temperature
        show_state: true
        state_adaptive_color: true
        aggregate_func: max
      - entity: sensor.klimerko_humidity
        name: Humidity
        show_state: true
        state_adaptive_color: true
        show_line: false
        show_points: true
        show_legend: true
        color: "#2AD4FF"
        y_axis: secondary
        aggregate_func: avg
    color_thresholds:
      - value: -40
        color: "#2AD4FF"
      - value: 16
        color: "#FFA500"
      - value: 29
        color: "#E53935"
    line_width: 4
    font_size_header: 13
    font_size: 70
    hours_to_show: 24
    points_per_hour: 3
    hour24: true
    animate: true
    show:
      icon: false
      fill: true
      labels: true
      labels_secondary: true
  - type: custom:mini-graph-card
    name: Outdoor PM10
    entities:
      - entity: sensor.klimerko_pm10
        show_state: true
        state_adaptive_color: true
    font_size_header: 13
    font_size: 70
    aggregate_func: avg
    decimals: 0
    hours_to_show: 24
    points_per_hour: 2
    line_width: 4
    color_thresholds:
      - value: 0
        color: "#17a355"
      - value: 54
        color: "#e9d109"
      - value: 154
        color: "#ff8c00"
      - value: 254
        color: "#ea270d"
      - value: 354
        color: "#7c2c85"
      - value: 424
        color: "#66001f"
    animate: true
    hour24: true
    show:
      graph: bar
      labels: true
      average: true
      extrema: true
      icon: false
  - type: custom:mini-graph-card
    name: Outdoor PM2.5
    entities:
      - entity: sensor.klimerko_pm2_5
        show_state: true
        state_adaptive_color: true
    font_size_header: 13
    font_size: 70
    aggregate_func: avg
    decimals: 0
    hours_to_show: 24
    points_per_hour: 2
    line_width: 4
    color_thresholds:
      - value: 0
        color: "#17a355"
      - value: 12
        color: "#e9d109"
      - value: 35
        color: "#ff8c00"
      - value: 55
        color: "#ea270d"
      - value: 150
        color: "#7c2c85"
      - value: 250
        color: "#66001f"
    animate: true
    hour24: true
    show:
      graph: bar
      labels: true
      average: true
      extrema: true
      icon: false
```

The final result will look something like this:

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

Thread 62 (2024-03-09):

Temp/humidity sensor requirement?

psyhomb, 2024-03-09:
Is this temp/humidity sensor required for this setup to work or we can assemble, flash and use Klimerko without it? Thanks

epiller, 2024-03-09:
Nope! You can actually use it without any sensors if you want to play around. I only mentioned that in the [2.0.0 release notes](https://github.com/DesconBelgrade/Klimerko/releases/tag/2.0.0) so I'll consider putting it in the main README as well.

From 2.0.0 release notes:
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

Closed 2024-03-11.

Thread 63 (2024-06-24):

Air Quality Sensor (PMS7003) i   Temperature/Humidity/Pressure Sensor (BME280)  stalno su off

ray00sd, 2024-06-24:
Pozdrav vec nekoliko dana pokusavam da ozivim klimerka..
dakle..koristim NDU ESP8266, senzore koji su navedeni u prospektu, pratio sam uputstvo sa tri NDU ploce i konstantno dobijam odgovor
------------------------------DATA------------------------------
[PMS] Air Quality Sensor (PMS7003) returned no data on data request this time.
[PMS] Air Quality Sensor (PMS7003) seems to be offline!
[BME] Temperature/Humidity/Pressure Sensor (BME280) returned no data this time.
[BME] Temperature/Humidity/Pressure Sensor (BME280) seems to be offline!

Sve je spojeno kako treba, BME280 imam sa 6 pinova u upotrebi su 4 prema uputstvu..
Koristim linux OS i dozvolio sam root upis preko usb porta..

Prelemio nekoliko puta konektrore, radio restart, flash...itd..nemam vise ideja i molim za sugestije..

ravenns, 2024-09-10:
Pozdrav,
Konekcija PM senzora na Vin nije dobra ako koristis USB konektor za napajanje uredjaja. Ako je to tvoj slucaj, onda treba koristiti Vu pin na kojem je 5V.

Sto se tice BM280 senzora, ni meni ne radi. Cudno se ponasa. Imam isto onaj sa 6 pinova. Pokusao sam da ga prikacim na sva 3 pina na kojima je 3V ali nece da radi (ne ocitava vrfednost). Plus je na jednom od tih pinova u koliziji sa PM senzorom koji zaglupi ako koristim taj 3V pin (sto nema smisla). Mislim da je moj BM280 neispravan, pa cu probati drugi.

ravenns, 2024-09-10:
Sada sam proverio, ovaj moj BME280 je ustvari BMP280.... Proveri pod mikroskopom, ako imas ili macro na kameri telefona. Ako vidis oznaku da pocinje sa "K" onda imas BMP280...

ravenns, 2024-09-30:
Pozdrav,
I ja se isto patim sa PMS7003 koji nasumicno ocitava. Od 10 puta, jednom ocita, ali vrednosti su nula. Ja koristim ESP8266 sa CH340.

Buljubasa, 2024-12-03:
Moj problem je druge prirode, u senzorima koji se razlikuju od onih pre nekog vremena.
Malo analizirajuci rad video sam da je problem sto se ne dize iz sleep moda, kada se podigne sve radi normalno.
Pokusavajuci svasta  na kraju je upalilo sto sam sledecu liniju:

    pms.wakeUp();

...Ponovio tako da ih ima ukupno pet zaredom.
Nije neko elegantno resenje ali sada radi ocitavanje PMS senzora svaki put i ostavicu tako dok ne dodje neka zvanicna zakrpa.
Razgovarao sam sa autorima, znaju za problem i izbacice novu verziju u skorije vreme.

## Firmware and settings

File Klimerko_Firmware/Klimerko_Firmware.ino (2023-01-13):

/*  ------------------------------------------- Project "KLIMERKO" ---------------------------------------------
 *  Citizen Air Quality measuring device with cloud monitoring, built at https://descon.me for the whole world.
 *  Programmed, built and maintained by Vanja Stanic // www.vanjastanic.com
 *  ------------------------------------------------------------------------------------------------------------
 *  This is a continued effort from https://descon.me/2018/winning-product/
 *  Supported by ISOC (Internet Society, Belgrade Chapter) // https://isoc.rs
 *  IoT Cloud Services and Communications SDK by AllThingsTalk // www.allthingstalk.com/
 *  3D Case for the device designed and manufactured by Dusan Nikic // nikic.dule@gmail.com
 *  ------------------------------------------------------------------------------------------------------------
 *  This sketch is downloaded from https://github.com/DesconBelgrade/Klimerko
 *  Head over there to read instructions and more about the project.
 *  Do not change anything in here unless you know what you're doing. Just upload this sketch to your device.
 *  You'll configure your WiFi and Cloud credentials once the sketch is uploaded to the device by 
 *  pressing the FLASH button on the NodeMCU for 2 seconds and connecting to Klimerko using any WiFi-enabled device.
 *  ------------------------------------------------------------------------------------------------------------
 *  Textual Air Quality Scale is based on PM10 criteria defined by RS Government (http://www.amskv.sepa.gov.rs/kriterijumi.php)
 *  Excellent (0-20), Good (21-40), Acceptable (41-50), Polluted (51-100), Very Polluted (Over 100)
 */

#include "src/AdafruitBME280/Adafruit_Sensor.h"
#include "src/AdafruitBME280/Adafruit_BME280.h"
#include "src/pmsLibrary/PMS.h"
#include "src/movingAvg/movingAvg.h"
#include "src/WiFiManager/WiFiManager.h"
#include "src/PubSubClient/PubSubClient.h"
#include "src/ArduinoJson-v6.18.5.h"
#include <SoftwareSerial.h>
#include <Wire.h>
#include <EEPROM.h>

#define BUTTON_PIN     0
#define pmsTX          D5
#define pmsRX          D6

// ------------------------- Device -----------------------------------------------------
String         firmwareVersion         = "2.1.1";
const char*    firmwareVersionPortal   = "<p>Firmware Version: 2.1.1</p>";
char           klimerkoID[32];

// -------------------------- WiFi ------------------------------------------------------
const int      wifiReconnectInterval   = 60;
bool           wifiConnectionLost      = true;
unsigned long  wifiReconnectLastAttempt;

// ------------------- WiFi Configuration Portal ----------------------------------------
char const     *wifiConfigPortalPassword = "ConfigMode"; // Password for WiFi Configuration Portal WiFi Network
const int      wifiConfigTimeout         = 1800;         // Seconds before WiFi Configuration expires
unsigned long  wifiConfigActiveSince;

// -------------------------- MQTT ------------------------------------------------------
const char*    MQTT_SERVER             = "api.allthingstalk.io";
const uint16_t MQTT_PORT               = 1883;
const char*    MQTT_PASSWORD           = "arbitrary";
uint16_t       MQTT_MAX_MESSAGE_SIZE   = 2048;
char           deviceId[32], deviceToken[64];

const int      mqttReconnectInterval   = 30; // Seconds between retries
bool           mqttConnectionLost      = true;
unsigned long  mqttReconnectLastAttempt;

char*          PM1_ASSET               = "pm1";
char*          PM2_5_ASSET             = "pm2-5";
char*          PM10_ASSET              = "pm10";
char*          AQ_ASSET                = "air-quality";
char*          TEMPERATURE_ASSET       = "temperature";
char*          TEMP_OFFSET_ASSET       = "temperature-offset";
char*          HUMIDITY_ASSET          = "humidity";
char*          PRESSURE_ASSET          = "pressure";
char*          INTERVAL_ASSET          = "interval";
char*          FIRMWARE_ASSET          = "firmware";
char*          WIFI_SIGNAL_ASSET       = "wifi-signal";

// -------------------------- BUTTON ------------------------------------------------------
const int      buttonLongPressTime     = 15000; // (milliseconds) Everything above this is considered a long press
const int      buttonMediumPressTime   = 1000;  // (milliseconds) Everything above this and below long press time is considered a medium press
const int      buttonShortPressTime    = 50;    // (milliseconds) Everything above this and below medium press time is considered a short press
unsigned long  buttonPressedTime       = 0;
unsigned long  buttonReleasedTime      = 0;
bool           buttonPressed           = false;
bool           buttonLongPressDetected = false;
int            buttonLastState         = HIGH;
int            buttonCurrentState;

// -------------------------- LED ---------------------------------------------------------
bool           ledState                = false;
bool           ledSuccessBlink         = false;
const int      ledBlinkInterval        = 1000;  // (milliseconds) How often to blink LED when there's no connection
unsigned long  ledLastUpdate;

// --------------------- SENSORS (GENERAL) ------------------------------------------------
uint8_t        dataPublishInterval     = 15;    // [MINUTES] Default sensor data sending interval
const uint8_t  sensorAverageSamples    = 10;    // Number of samples used to average values from sensors
const int      sensorRetriesUntilConsideredOffline = 3;
bool           dataPublishFailed       = false; // Keeps track if a payload has failed to send so we can retry
unsigned long  sensorReadTime, dataPublishTime;

// -------------------------- PMS7003 -----------------------------------------------------
const uint8_t  pmsWakeBefore           = 30;    // [SECONDS] Seconds PMS sensor should be active before reading it
bool           pmsSensorOnline         = true;
int            pmsSensorRetry          = 0;
bool           pmsNoSleep              = false;
bool           pmsWoken                = false;
const char     *airQuality, *airQualityRaw;
int            avgPM1, avgPM25, avgPM10;

// -------------------------- BME280 -----------------------------------------------------
bool           bmeSensorOnline                = true;
int            bmeSensorRetry                 = 0;
float          bmeTemperatureOffset           = -4;   // Default temperature offset
char           bmeTemperatureOffsetChar[8];           // Used for WiFi Configuration Portal and memory
const char     bmeTemperatureOffsetDefault[8] = "-4"; // Used for WiFi Configuration Portal and memory
const int      bmeTemperatureOffsetMax        = 25;
const int      bmeTemperatureOffsetMin        = -25;
float          avgTemperature, avgHumidity, avgPressure;

// -------------------------- MEMORY -----------------------------------------------------
const uint16_t EEPROM_attStartAddress  = 0;
const uint16_t EEPROMsize              = 256;

// -------------------------- OBJECTS -----------------------------------------------------
WiFiManager wm;
WiFiManagerParameter portalDeviceID("device_id", "AllThingsTalk Device ID", deviceId, 32);
WiFiManagerParameter portalDeviceToken("device_token", "AllThingsTalk Device Token", deviceToken, 64);
WiFiManagerParameter portalTemperatureOffset("temperature_offset", "Temperature Offset", bmeTemperatureOffsetChar, 8);
WiFiManagerParameter portalDisplayFirmwareVersion(firmwareVersionPortal);
WiFiManagerParameter portalDisplayCredits("Firmware Designed and Developed by Vanja Stanic");
WiFiClient networkClient;
PubSubClient mqtt(networkClient);
SoftwareSerial pmsSerial(pmsTX, pmsRX);
PMS pms(pmsSerial);
PMS::DATA data;
Adafruit_BME280 bme;
movingAvg pm1(sensorAverageSamples);
movingAvg pm25(sensorAverageSamples);
movingAvg pm10(sensorAverageSamples);
movingAvg temp(sensorAverageSamples);
movingAvg hum(sensorAverageSamples);
movingAvg pres(sensorAverageSamples);

void sensorLoop() { // Reads and publishes sensor data and wakes up pms sensor in predefined intervals
  // Check if it's time to wake up PMS7003
  if (millis() - sensorReadTime >= readIntervalMillis() - (pmsWakeBefore * 1000) && !pmsWoken && pmsSensorOnline) {
    Serial.println("[PMS] Now waking up Air Quality Sensor");
    pmsPower(true);
  }
  
  // Read sensor data
  if (millis() - sensorReadTime >= readIntervalMillis()) {
    sensorReadTime = millis();
    readSensorData();
  }

  // Send average sensor data
  if (millis() - dataPublishTime >= dataPublishInterval * 60000) {
    if (!wifiConnectionLost) {
      if (!mqttConnectionLost) {
        dataPublishFailed = false;
        dataPublishTime = millis();
        publishSensorData();
      } else {
        if (!dataPublishFailed) {
          Serial.println("[DATA] Can't send sensor data because Klimerko is not connected to AllThingsTalk");
          dataPublishFailed = true;
        }
      }
    } else {
      if (!dataPublishFailed) {
        Serial.println("[DATA] Can't send sensor data because Klimerko is not connected to WiFi");
        dataPublishFailed = true;
      }
    }
  }
}

void readSensorData() {
  Serial.println("------------------------------DATA------------------------------");
  readPMS();
  readBME();
  Serial.println("----------------------------------------------------------------");
  if (!pmsNoSleep && pmsSensorOnline) {
    Serial.print("[PMS] Air Quality Sensor will sleep until ");
    Serial.print(pmsWakeBefore);
    Serial.println(" seconds before next reading.");
    pmsPower(false);
  }
}

void publishSensorData() {
  char JSONmessageBuffer[512];
  DynamicJsonDocument doc(512);
  if (pmsSensorOnline) {
    JsonObject airQualityJson = doc.createNestedObject(AQ_ASSET);
    airQualityJson["value"] = airQuality;
    JsonObject pm1Json = doc.createNestedObject(PM1_ASSET);
    pm1Json["value"] = avgPM1;
    JsonObject pm25Json = doc.createNestedObject(PM2_5_ASSET);
    pm25Json["value"] = avgPM25;
    JsonObject pm10Json = doc.createNestedObject(PM10_ASSET);
    pm10Json["value"] = avgPM10;
  } else {
    Serial.println("[DATA] Won't send Air Quality Sensor (PMS7003) data because it seems to be offline.");
  }
  if (bmeSensorOnline) {
    JsonObject temperatureJson = doc.createNestedObject(TEMPERATURE_ASSET);
    temperatureJson["value"] = avgTemperature;
    JsonObject humidityJson = doc.createNestedObject(HUMIDITY_ASSET);
    humidityJson["value"] = avgHumidity;
    JsonObject pressureJson = doc.createNestedObject(PRESSURE_ASSET);
    pressureJson["value"] = avgPressure;
  } else {
    Serial.println("[DATA] Won't send Temperature/Humidity/Pressure Sensor (BME280) data because it seems to be offline.");
  }
  JsonObject firmwareJson = doc.createNestedObject(FIRMWARE_ASSET);
  firmwareJson["value"] = firmwareVersion;
  JsonObject wifiJson = doc.createNestedObject(WIFI_SIGNAL_ASSET);
  wifiJson["value"] = wifiSignal();
  serializeJson(doc, JSONmessageBuffer);

  char topic[128];
  snprintf(topic, sizeof topic, "%s%s%s", "device/", deviceId, "/state");
  mqtt.publish(topic, JSONmessageBuffer, false);
  Serial.print("[DATA] Published sensor data to AllThingsTalk: ");
  Serial.println(JSONmessageBuffer);
}

void readPMS() { // Function that reads data from the PMS7003
  while (pmsSerial.available()) { pmsSerial.read(); }
  pms.requestRead(); // Now get the real data
  
  if (pms.readUntil(data)) {
    int PM1 = data.PM_AE_UG_1_0;
    int PM2_5 = data.PM_AE_UG_2_5;
    int PM10 = data.PM_AE_UG_10_0;

    avgPM1 = pm1.reading(PM1);
    avgPM25 = pm25.reading(PM2_5);
    avgPM10 = pm10.reading(PM10);

    // Assign a text value of how good the air is based on current value
    // http://www.amskv.sepa.gov.rs/kriterijumi.php
    if (PM10 <= 20) {
      airQualityRaw = "Excellent";
    } else if (PM10 >= 21 && PM10 <= 40) {
      airQualityRaw = "Good";
    } else if (PM10 >= 41 && PM10 <= 50) {
      airQualityRaw = "Acceptable";
    } else if (PM10 >= 51 && PM10 <= 100) {
      airQualityRaw = "Polluted";
    } else if (PM10 > 100) {
      airQualityRaw = "Very Polluted";
    }

    // Assign a text value of how good the air is based on average value
    // http://www.amskv.sepa.gov.rs/kriterijumi.php
    if (avgPM10 <= 20) {
      airQuality = "Excellent";
    } else if (avgPM10 >= 21 && avgPM10 <= 40) {
      airQuality = "Good";
    } else if (avgPM10 >= 41 && avgPM10 <= 50) {
      airQuality = "Acceptable";
    } else if (avgPM10 >= 51 && avgPM10 <= 100) {
      airQuality = "Polluted";
    } else if (avgPM10 > 100) {
      airQuality = "Very Polluted";
    }

    // Print via SERIAL
    Serial.print("Air Quality is ");
    Serial.print(airQualityRaw);
    Serial.print(" (Average: ");
    Serial.print(airQuality);
    Serial.println(")");
    Serial.print("PM 1:          ");
    Serial.print(PM1);
    Serial.print(" µg/m³ (Average: ");
    Serial.print(avgPM1);
    Serial.println(")");
    Serial.print("PM 2.5:        ");
    Serial.print(PM2_5);
    Serial.print(" µg/m³ (Average: ");
    Serial.print(avgPM25);
    Serial.println(")");
    Serial.print("PM 10:         ");
    Serial.print(PM10);
    Serial.print(" µg/m³ (Average: ");
    Serial.print(avgPM10);
    Serial.println(")");

    pmsSensorRetry = 0;
    if (!pmsSensorOnline) {
      pmsSensorOnline = true;
      Serial.println("[PMS] Air Quality Sensor (PMS7003) seems to be back online!");
    }
  } else {
    if (pmsSensorOnline) {
      Serial.println("[PMS] Air Quality Sensor (PMS7003) returned no data on data request this time.");
      pmsSensorRetry++;
      if (pmsSensorRetry > sensorRetriesUntilConsideredOffline) {
        pmsSensorOnline = false;
        Serial.println("[PMS] Air Quality Sensor (PMS7003) seems to be offline!");
        pm1.reset();
        pm25.reset();
        pm10.reset();
        initPMS();
      }
    } else {
      Serial.println("[PMS] Air Quality Sensor (PMS7003) is offline.");
      initPMS();
    }
  }
}

void readBME() { // Function for reading data from the BME280 Sensor
  float temperatureRaw = bme.readTemperature();
  float temperature    = temperatureRaw + bmeTemperatureOffset;
  float humidityRaw    = bme.readHumidity();
  float humidity       = humidityRaw * exp(243.12 * 17.62 * (temperatureRaw - temperature) / (243.12 + temperatureRaw) / (243.12 + temperature)); // Compensates the RH in accordance to temperature offset so the RH isn't wrong when the temp is offset
  float pressure       = bme.readPressure() / 100.0F;

  if (temperatureRaw > -100 && temperatureRaw < 150 && humidity >= 0 && humidity <= 100) {
    avgTemperature = temp.reading(temperature*100);
    avgTemperature = avgTemperature/100;
    avgHumidity    = hum.reading(humidity*100);
    avgHumidity    = avgHumidity/100;
    avgPressure    = pres.reading(pressure*100);
    avgPressure    = avgPressure/100;

    Serial.print("Temperature:   ");
    Serial.print(temperature);
    Serial.print("°C (Average: ");
    Serial.print(avgTemperature);
    Serial.print(", Raw: ");
    Serial.print(temperatureRaw);
    Serial.print(", Offset: ");
    Serial.print(bmeTemperatureOffset);
    Serial.println(")");
    Serial.print("Humidity:      ");
    Serial.print(humidity);
    Serial.print(" % (Average: ");
    Serial.print(avgHumidity);
    Serial.print(", Raw: ");
    Serial.print(humidityRaw);
    Serial.println(")");
    Serial.print("Pressure:      ");
    Serial.print(pressure);
    Serial.print(" mbar (Average: ");
    Serial.print(avgPressure);
    Serial.println(")");

    bmeSensorRetry = 0;
    if (!bmeSensorOnline) {
      bmeSensorOnline = true;
      Serial.println("[BME] Temperature/Humidity/Pressure Sensor (BME280) is back online!");
    }
  } else {
    if (bmeSensorOnline) {
      Serial.println("[BME] Temperature/Humidity/Pressure Sensor (BME280) returned no data this time.");
      bmeSensorRetry++;
      if (bmeSensorRetry > sensorRetriesUntilConsideredOffline) {
        bmeSensorOnline = false;
        Serial.println("[BME] Temperature/Humidity/Pressure Sensor (BME280) seems to be offline!");
        temp.reset();
        hum.reset();
        pres.reset();
        initBME();
      }
    } else {
      Serial.println("[BME] Temperature/Humidity/Pressure Sensor (BME280) is offline.");
      initBME();
    }
  }
}

void pmsPower(bool state) { // Controls sleep state of PMS sensor
  if (state) {
    pms.wakeUp();
    pms.passiveMode();
    pmsWoken = true;
  } else {
    pmsSerial.flush();
    unsigned long now = millis();
    while(millis() < now + 100);
    pmsWoken = false;
    pms.sleep();
  }
}
 
void changeInterval(int interval) { // Changes sensor data reporting interval
  if (interval > 5 && interval <= 60) {
    dataPublishInterval = interval;
    pmsNoSleep = false;
    Serial.print("[DATA] Device reporting interval set to ");
    Serial.print(interval);
    Serial.println(" minutes");
    Serial.print("[DATA] Sensor data will be read every ");
    Serial.print(readIntervalSeconds());
    Serial.println(" seconds for averaging.");
    publishDiagnosticData();
  } else if (interval <= 1) {
    dataPublishInterval = 1;
    pmsNoSleep = true;
    pmsPower(true);
    Serial.println("[DATA] Reporting interval set to 1 minute (minimum).");
    Serial.print("[DATA] Sensor data will be read every ");
    Serial.print(readIntervalSeconds());
    Serial.println(" seconds for averaging.");
    Serial.println("[DATA] This prevents sleeping of Air Quality Sensor and reduces its lifespan.");
    publishDiagnosticData();
  } else if (interval <= 5) {
    dataPublishInterval = interval;
    pmsNoSleep = true;
    pmsPower(true);
    Serial.print("[DATA] Device reporting interval set to ");
    Serial.print(interval);
    Serial.println(" minutes");
    Serial.print("[DATA] Sensor data will be read every ");
    Serial.print(readIntervalSeconds());
    Serial.println(" seconds for averaging.");
    Serial.println("[DATA] This prevents sleeping of Air Quality Sensor and reduces its lifespan.");
    publishDiagnosticData();
  } else if (interval >= 60) {
    dataPublishInterval = 60;
    pmsNoSleep = false;
    Serial.print("[DATA] Device reporting interval set to ");
    Serial.print(dataPublishInterval);
    Serial.println(" minutes");
    Serial.print("[DATA] Sensor data will be read every ");
    Serial.print(readIntervalSeconds());
    Serial.println(" seconds for averaging.");
    publishDiagnosticData();
  }
}

void publishDiagnosticData() { // Publishes diagnostic data to AllThingsTalk
  if (!wifiConnectionLost) {
    if (!mqttConnectionLost) {
      char JSONmessageBuffer[256];
      DynamicJsonDocument doc(256);
      JsonObject dataPublishIntervalJson = doc.createNestedObject(INTERVAL_ASSET);
      dataPublishIntervalJson["value"] = dataPublishInterval;
      JsonObject firmwareJson = doc.createNestedObject(FIRMWARE_ASSET);
      firmwareJson["value"] = firmwareVersion;
      JsonObject wifiJson = doc.createNestedObject(WIFI_SIGNAL_ASSET);
      wifiJson["value"] = wifiSignal();
      JsonObject tempOffsetJson = doc.createNestedObject(TEMP_OFFSET_ASSET);
      tempOffsetJson["value"] = bmeTemperatureOffset;
      serializeJson(doc, JSONmessageBuffer);
    
      char topic[256];
      snprintf(topic, sizeof topic, "%s%s%s", "device/", deviceId, "/state");
      mqtt.publish(topic, JSONmessageBuffer, false);
      Serial.print("[DATA] Published diagnostic data to AllThingsTalk: ");
      Serial.println(JSONmessageBuffer);
    } else {
      Serial.println("[DATA] Can't send diagnostic data because Klimerko is not connected to AllThingsTalk");
    }
  } else {
    Serial.println("[DATA] Can't send diagnostic data because Klimerko is not connected to WiFi");
  }
}

unsigned long readIntervalMillis() {
  unsigned long result = (dataPublishInterval * 60000) / sensorAverageSamples;
  return result;
}

int readIntervalSeconds() {
  int result = (dataPublishInterval * 60) / sensorAverageSamples;
  return result;
}
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
void loop() {
  sensorLoop();
  maintainWiFi();
  maintainMQTT();
  wifiConfigLoop();
  buttonLoop();
  ledLoop();  
}

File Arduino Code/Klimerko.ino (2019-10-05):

/*  This is taken from https://github.com/DesconBelgrade/Klimerko
 *  Please head over there to read more about the project.
 * 
 *  --------------- Project "KLIMERKO" ---------------
 *  Citizen Air Quality measuring device with cloud monitoring, built at https://descon.me for the whole world.
 *  This is a continued effort from https://descon.me/2018/winning-product/ supported by Beogradska Otvorena Skola // www.bos.rs
 *  Project is powered by IoT Cloud Services and SDK from AllThingsTalk // www.allthingstalk.com
 *  3D Case for the device designed and built by Dusan Nikic
 *  Device designed, coded and built by Vanja Stanic // www.vanjastanic.com
*/

#include "src/AllThingsTalk/AllThingsTalk.h"
#include "src/AdafruitUnifiedSensor/Adafruit_Sensor.h"
#include "src/AdafruitBME280/Adafruit_BME280.h"
#include "src/pmsLibrary/PMS.h"
#include <SoftwareSerial.h>
#include <Wire.h>

// ----------- CUSTOMIZABLE PART BEGIN -----------

// Your WiFi and Device Credentials here
auto wifiCreds = WifiCredentials("WIFI_SSID","WIFI_PASSWORD");
auto deviceCreds = DeviceConfig("YOUR_DEVICE_ID","YOUR_DEVICE_TOKEN");
auto device = Device(wifiCreds, deviceCreds);

// ----------- CUSTOMIZABLE PART END -------------

// Pins to which the PMS7003 is connected to
const uint8_t pmsTX = D5;
const uint8_t pmsRX = D6;

// Assets to be published to
char* PM1_ASSET         = "pm1";
char* PM2_5_ASSET       = "pm2-5";
char* PM10_ASSET        = "pm10";
char* AQ_ASSET          = "air-quality";
char* TEMPERATURE_ASSET = "temperature";
char* HUMIDITY_ASSET    = "humidity";
char* PRESSURE_ASSET    = "pressure";
char* INTERVAL_ASSET    = "interval";

// Other variables
int readInterval = 15; // [MINUTES] Default device reporting time
int wakeInterval = 30; // [SECONDS] Seconds to activate sensor before reading it
const char*   airQuality;
unsigned long lastReadTime;
unsigned long currentTime;
bool firstReading = true;
bool pmsWoken = false;

// Sensor initialization
Adafruit_BME280 bme;
SoftwareSerial pmsSerial(pmsTX, pmsRX);
PMS pms(pmsSerial);
PMS::DATA data;
CborPayload payload;

// Runs at boot
void setup() {
  Serial.begin(115200);
  pmsSerial.begin(9600);
  pms.passiveMode();
  bme.begin(0x76);
  Serial.println();
  Serial.println("Project 'KLIMERKO' - https://github.com/DesconBelgrade/Klimerko");
  device.debugPort(Serial);
  device.wifiSignalReporting(true);
  device.connectionLed(true);
  device.setActuationCallback(INTERVAL_ASSET, controlInterval);
  device.init();
  publishInterval();
}

// Function to read both sensors at the same time
void readSensors() {
  currentTime = millis();
  if (currentTime - lastReadTime >= (readInterval * 60000) - (wakeInterval * 1000) && !pmsWoken) {
    Serial.println("System: Now waking up PMS7003");
    pms.wakeUp();
    pms.passiveMode();
    pmsWoken = true;
  }
  if (currentTime - lastReadTime >= readInterval * 60000) {
    payload.reset();
    readBME();
    readPMS();
    device.send(payload);
    lastReadTime = currentTime;
  }
}

// Function for reading data from the BME280 Sensor
void readBME() {
  // Save the current BME280 sensor data
  float temperatureRaw = bme.readTemperature();
  float humidityRaw = bme.readHumidity();
  float pressureRaw = bme.readPressure() / 100.0F;

  static char temperature[7];
  dtostrf(temperatureRaw, 6, 1, temperature);
  static char humidity[7];
  dtostrf(humidityRaw, 6, 1, humidity);
  static char pressure[7];
  dtostrf(pressureRaw, 6, 0, pressure);

  // Print data to Serial port
  Serial.println("-----------BME280-----------");
  Serial.print("Temperature: ");
  Serial.println(temperature);
  Serial.print("Humidity:    ");
  Serial.println(humidity);
  Serial.print("Pressure:   ");
  Serial.println(pressure);
  Serial.println("----------------------------");

  // Add data to payload to be sent to AllThingsTalk
  payload.set(TEMPERATURE_ASSET, temperature);
  payload.set(HUMIDITY_ASSET, humidity);
  payload.set(PRESSURE_ASSET, pressure);
}

// Function that reads data from the PMS7003
void readPMS() {
  pms.requestRead();
  delay(1000);
  pms.requestRead();
  
  if (pms.readUntil(data)) {
    // Save the current Air Quality sensor data
    int PM1 = data.PM_AE_UG_1_0;
    int PM2_5 = data.PM_AE_UG_2_5;
    int PM10 = data.PM_AE_UG_10_0;
    
    // Assign a text value of how good the air is
    if (PM2_5 <= 30) {
      airQuality = "Excellent";
    } else if (PM2_5 >= 31 && PM2_5 <= 60) {
      airQuality = "Good";
    } else if (PM2_5 >= 61 && PM2_5 <= 90) {
      airQuality = "Medium";
    } else if (PM2_5 >= 91 && PM2_5 <= 120) {
      airQuality = "Poor";
    } else if (PM2_5 >= 121 && PM2_5 <= 250) {
      airQuality = "Very poor";
    } else if (PM2_5 > 250) {
      airQuality = "Terrible";
    }

    // Print via SERIAL
    Serial.println("----------PMS7003-----------");
    Serial.print("Air Quality is ");
    Serial.println(airQuality);
    Serial.print("PM 1.0 (ug/m3):  ");
    Serial.println(PM1);
    Serial.print("PM 2.5 (ug/m3):  ");
    Serial.println(PM2_5);
    Serial.print("PM 10.0 (ug/m3): ");
    Serial.println(PM10);
    Serial.println("----------------------------");

    // Add data to payload to be sent to AllThingsTalk
    payload.set(PM1_ASSET, PM1);
    payload.set(PM2_5_ASSET, PM2_5);
    payload.set(PM10_ASSET, PM10);
    payload.set(AQ_ASSET, airQuality);

    Serial.print("System: Putting PMS7003 to sleep until ");
    Serial.print(wakeInterval);
    Serial.println(" seconds before next reading.");
    pms.sleep();
    pmsWoken = false;
  } else {
    Serial.println("System Error: Air Quality Sensor (PMS7003) returned no data on data request this time.");
    pms.sleep();
    pmsWoken = false;
  }
}

// Function that's called once a user sets the interval 
void controlInterval(int interval) {
  if (interval != 0) {
    readInterval = interval;
    Serial.print("System: Device reporting interval changed to ");
    Serial.print(interval);
    Serial.println(" minute");
    publishInterval();
  } else {
    Serial.println("System Error: Attempted to set device reporting interval to 0. No changes made.");
    publishInterval();
  }
}

// Function (called at boot in setup()) that publishes the current data sending interval value to AllThingsTalk
void publishInterval() {
  Serial.println("System: Publishing the actual device reporting interval to AllThingsTalk");
  device.send(INTERVAL_ASSET, readInterval);
}

void loop() {
  device.loop(); // Keep the connection to AllThingsTalk alive
  readSensors(); // Read data from sensors
}

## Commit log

2019-10-23 input fixes for linux :)
    [Klimerko_Firmware.ino]
2019-10-23 Fixed issues with linux
    [Klimerko_Firmware.ino]
2019-10-23 Fixed issue with cancelling credentials change
    Changing credentials and then exiting the dialog (not saving changes) made changes to the current session because new values were being saved to the same place as old values. This is now fixed and version is bumped to v1.1.2
    [Klimerko_Firmware.ino]
2019-11-06 Bug fixes and PMS7003 improvements
    Bump to version v1.1.4; Improved PMS7003 realibility when reading (or when failing to read due to a physical disconnect and reconnect later). Fixed issue introduced in last version where data could not be sent. If you're on v1.1.3, please update to this version.
    [Klimerko_Firmware.ino]
2019-12-13 Fixed issue with unique device id generation that could prevent it from connecting
    [Klimerko_Firmware.ino]
2020-01-07 Fixed temperature readings by taking into account the self-heating of BME280 and heat transfer from NodeMCU to BME280 when inside the 3D printed case.
    [Klimerko_Firmware.ino]
2020-01-08 Updated to use the AllThingsTalk SDK; Device now reports its firmware version to the cloud
2020-01-15 Version 1.3.0 beta: Averaging of data, dynamic adjustment of sensor readings, calibrated temperature readings, code refactoring, stability improvements
    [Klimerko_Firmware.ino]
2020-01-27 Added fixes for textual pollution level reference values
    [Klimerko_Firmware.ino]
2020-01-27 Added Klimerko 3D Printed Case STL files! Cheers!
    [Base.STL, Cover.STL, Stand.STL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]
2020-01-27 Added extra photos of 3D case
2020-01-27 Added printable case notices
2020-01-28 Added instructions to check Arduino version when updating firmware
2020-02-02 Added 3D printable "Clamp" holder for Klimerko
    [Base.STL, Clamp Protector.stl, Clamp Thread.stl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]
2020-02-03 Added new Klimerko Pole Mount 3D files (by Filip)
    [Pole Mount (Round, Horizontal, 50mm).stl, Pole Mount (Round, Vertical, 20mm).stl, Pole Mount (Square, Vertical, 30mm).stl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]
2021-02-24 Klimerko Firmware v1.3.1
    - Utilize new version of AllThingsTalk WiFi SDK (v2.1.2) which fixes a memory leak issue and utilizes a new way of checking if WiFi is connected.
    - Minor fixes to variable types & ogranization
    - Update website link
    [Klimerko_Firmware.ino]
2021-12-10 Added readSensorData and publishSensorData
    Added "readSensorData" and "publishSensorData", switched off WiFiManager debug output for cleaner serial, removed AllThingsTalk Device Token from Serial output, added local IP printing when first con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
2021-12-12 Added publishing of diagnostic data at every MQTT connect
    Includes device reporting interval, firmware version and WiFi signal strength
2021-12-12 Extended MQTT keepalive and fixed some serial prints
    [Klimerko_Firmware.ino]
2021-12-12 Extended keepalive and fixed some serial prints
2021-12-12 Tidied up WiFi serial prints
2021-12-13 Added feature to constantly retry sending data if it failed to send
    [Klimerko_Firmware.ino]
2021-12-13 Added backup WiFi reconnect in case main reconnect fails
    [Klimerko_Firmware.ino]
2021-12-13 Implemented averaging with decimals for temperature, humidity & pressure
2021-12-13 Increased sensor retries before considered offline and fixed PMS sensor recovering
    [Klimerko_Firmware.ino]
2022-09-14 Added Configurable Temperature Offset
    Added new feature in order to accommodate different Klimerko builds where the temperature offset isn't the same as the default one. Also contains general fixes and improvements.
    [Klimerko_Firmware.ino]
2022-09-14 Added Configurable Temperature Offset to README
2022-10-11 changing arduino url
2023-01-13 Added CP2102 Windows drivers to README
2023-01-13 Fixed some compiler issues, bumped to 2.1.1
    [Klimerko_Firmware.ino]
